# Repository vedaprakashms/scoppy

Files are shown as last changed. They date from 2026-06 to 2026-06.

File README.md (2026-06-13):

# scoppy
PI Pico ossciloscope using simple components

The project contains multiple directory, each with its own kind of Scopy, i.e Surface mountable, through hole, etc...

The Directory names are self explanatory. 

# IMAGES

## Scoppy SMD Single sided PCB
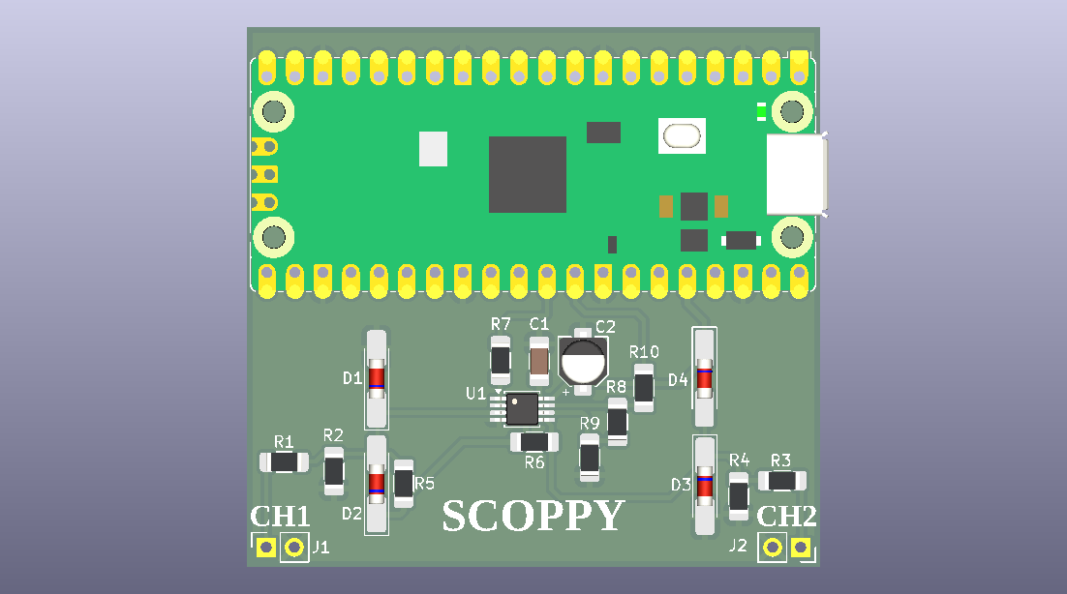
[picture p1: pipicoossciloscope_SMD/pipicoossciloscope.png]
SCOPPY SMD single sided Single sided pcb front view


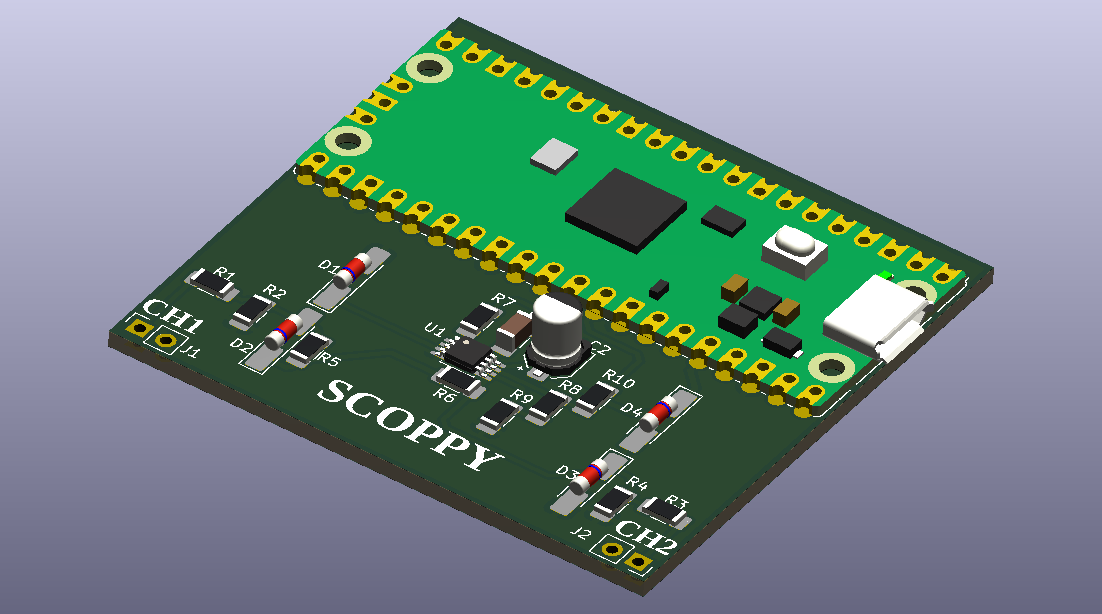
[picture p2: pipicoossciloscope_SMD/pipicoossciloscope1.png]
SCOPPY SMD Single Side Ortho Single sided PCB Ortho View.


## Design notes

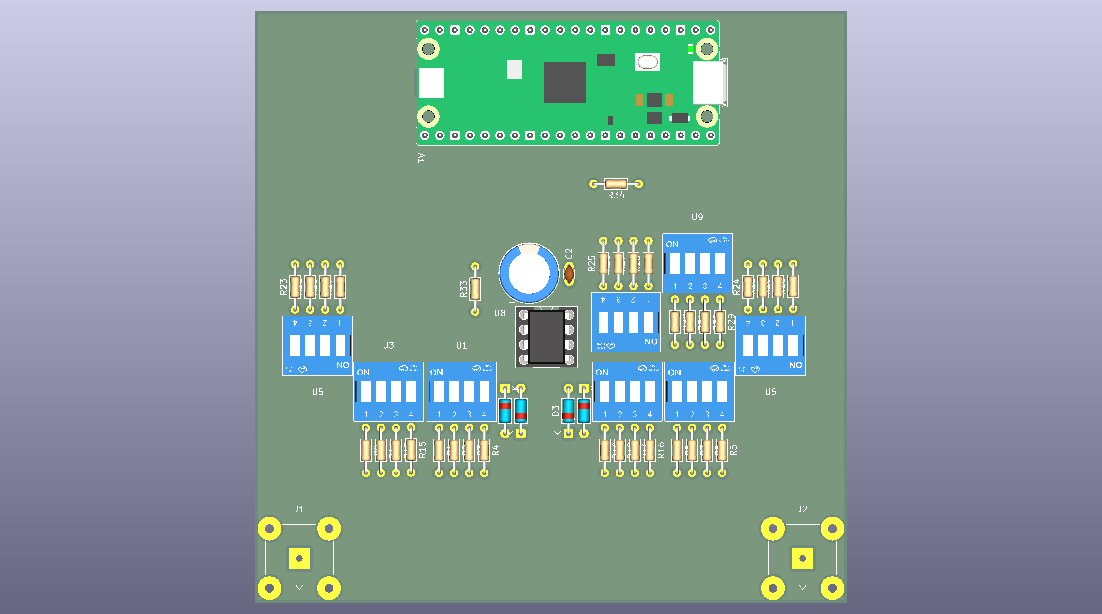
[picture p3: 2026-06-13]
PiPicoOssciloscope_THT/PiPicoOssciloscope_THT.png

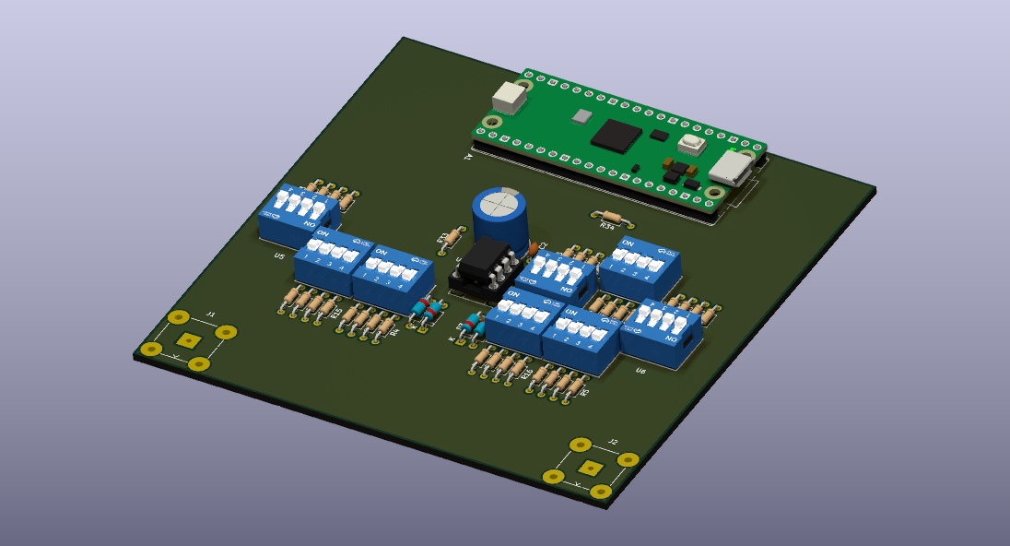
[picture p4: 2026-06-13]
PiPicoOssciloscope_THT/PiPicoOssciloscope_THT_1.png

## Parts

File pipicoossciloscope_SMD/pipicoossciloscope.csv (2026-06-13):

Reference | Qty | Value | DNP | Exclude from BOM | Exclude from Board | Footprint | Datasheet
A1 | 1 | RaspberryPi_Pico |  |  |  | Module:RaspberryPi_Pico_Common_Unspecified | https://datasheets.raspberrypi.com/pico/pico-datasheet.pdf
C1 | 1 | C |  |  |  | Capacitor_SMD:C_1206_3216Metric_Pad1.33x1.80mm_HandSolder
C2 | 1 | C_Polarized |  |  |  | Capacitor_SMD:CP_Elec_4x5.4
D1,D2,D3,D4 | 4 | LL4148 |  |  |  | Diode_SMD:D_MiniMELF_Handsoldering | http://www.vishay.com/docs/85557/ll4148.pdf
J1,J2 | 2 | Conn_01x02_Socket |  |  |  | Connector_PinSocket_2.54mm:PinSocket_1x02_P2.54mm_Vertical
R1,R2,R3,R4,R5,R6,R7,R8,R9,R10 | 10 | R |  |  |  | Resistor_SMD:R_1206_3216Metric_Pad1.30x1.75mm_HandSolder
U1 | 1 | MCP6002-xMS |  |  |  | Package_SO:MSOP-8_3x3mm_P0.65mm | http://ww1.microchip.com/downloads/en/DeviceDoc/21733j.pdf

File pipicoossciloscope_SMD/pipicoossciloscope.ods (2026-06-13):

Reference | Qty | Value | Individual cost | Total Cost | DNP | Exclude from BOM | Exclude from Board | Footprint | Datasheet
A1 | 1 | RaspberryPi_Pico | 250 | 250 |  |  |  | Module:RaspberryPi_Pico_Common_Unspecified | https://datasheets.raspberrypi.com/pico/pico-datasheet.pdf
C1 | 1 | C | 1 | 1 |  |  |  | Capacitor_SMD:C_1206_3216Metric_Pad1.33x1.80mm_HandSolder
C2 | 1 | C_Polarized | 2 | 2 |  |  |  | Capacitor_SMD:CP_Elec_4x5.4
D1,D2,D3,D4 | 4 | LL4148 | 1 | 4 |  |  |  | Diode_SMD:D_MiniMELF_Handsoldering | http://www.vishay.com/docs/85557/ll4148.pdf
J1,J2 | 2 | Conn_01x02_Socket | 0 | 0 |  |  |  | Connector_PinSocket_2.54mm:PinSocket_1x02_P2.54mm_Vertical
R1,R2,R3,R4,R5,R6,R7,R8,R9,R10 | 10 | R | 0.2 | 2 |  |  |  | Resistor_SMD:R_1206_3216Metric_Pad1.30x1.75mm_HandSolder
U1 | 1 | MCP6002-xMS | 40 | 40 |  |  |  | Package_SO:MSOP-8_3x3mm_P0.65mm | http://ww1.microchip.com/downloads/en/DeviceDoc/21733j.pdf
 | 1 | Others | 200 | 200
 |  |  |  | 499

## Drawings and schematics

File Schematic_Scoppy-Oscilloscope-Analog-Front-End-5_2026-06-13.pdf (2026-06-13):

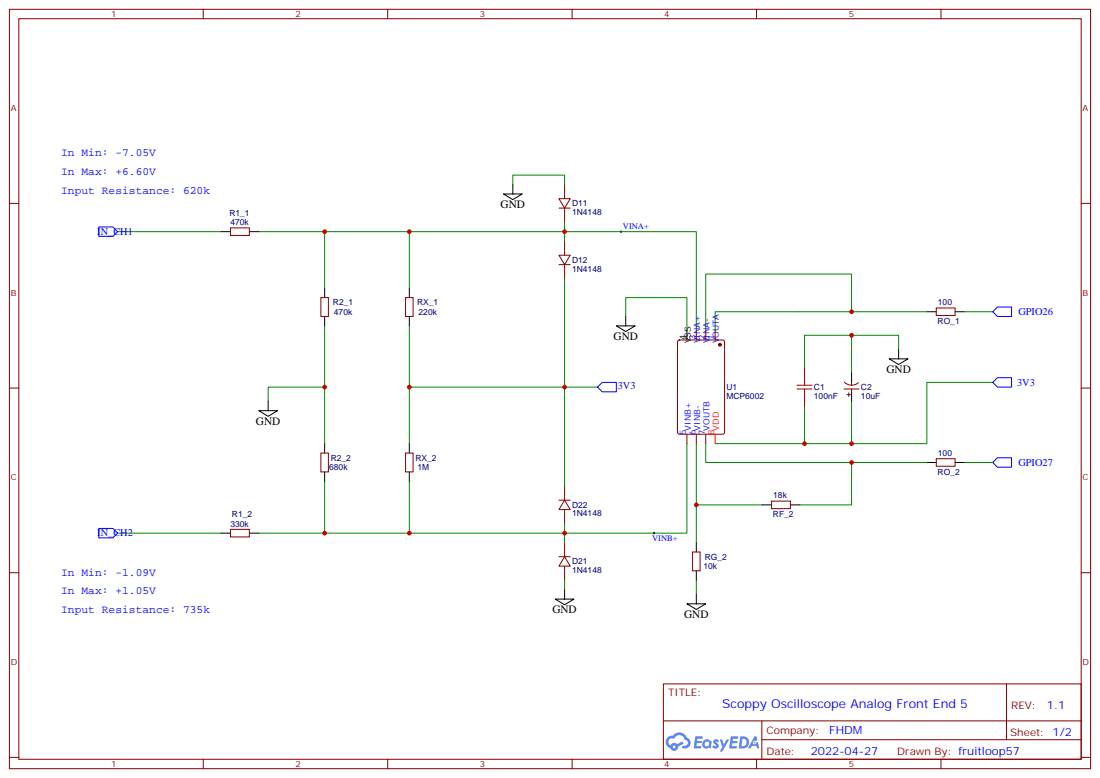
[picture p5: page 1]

MCP6282, MCP6292

## Examples of other voltage ranges

## Alternative Op-Amps

GAIN: 1.67

Note: 'In Min' and 'In Max' are the values you enter as the voltage ranges in the Scoppy app

In Min: -10.2V
In Max: +10.1V
Input Resistance: 812k

R1: 680k
R2: 330k
RX: 220k
GAIN: Unity
RF: NONE
RG: NONE | RG: NONE | RG: 22k | RG: 15k RF: 10k

RX: 560k

R2: 680k

R1: 330k

Input Resistance: 637k

In Max: +2.16V

In Min: -1.94V

RF: 12k

GAIN: 1.55

RX: 470k

R2: 470k

R1: 470k

Input Resistance: 705k

In Max: +3.11V

In Min: -3.30V

RF: NONE

GAIN: Unity

RX: 220k

R2: 680k

R1: 330k

Input Resistance: 496k

In Max: +4.01V

In Min: -4.95V
A | A
B | B
C | C
D | D

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
TITLE:
Scoppy Oscilloscope Analog Front End 5 | REV: 1.0
Date: | 2022-05-17

Sheet: 2/2
Drawn By: fruitloop57

Company: FHDM
https://github.com/fhdm-dev/scoppy

RG: NONE

RF: NONE

GAIN: Unity

RX: 150k

R2: 180k

R1: 820k

Input Resistance: 902k

In Max: +18.3V

In Min: -18.0V

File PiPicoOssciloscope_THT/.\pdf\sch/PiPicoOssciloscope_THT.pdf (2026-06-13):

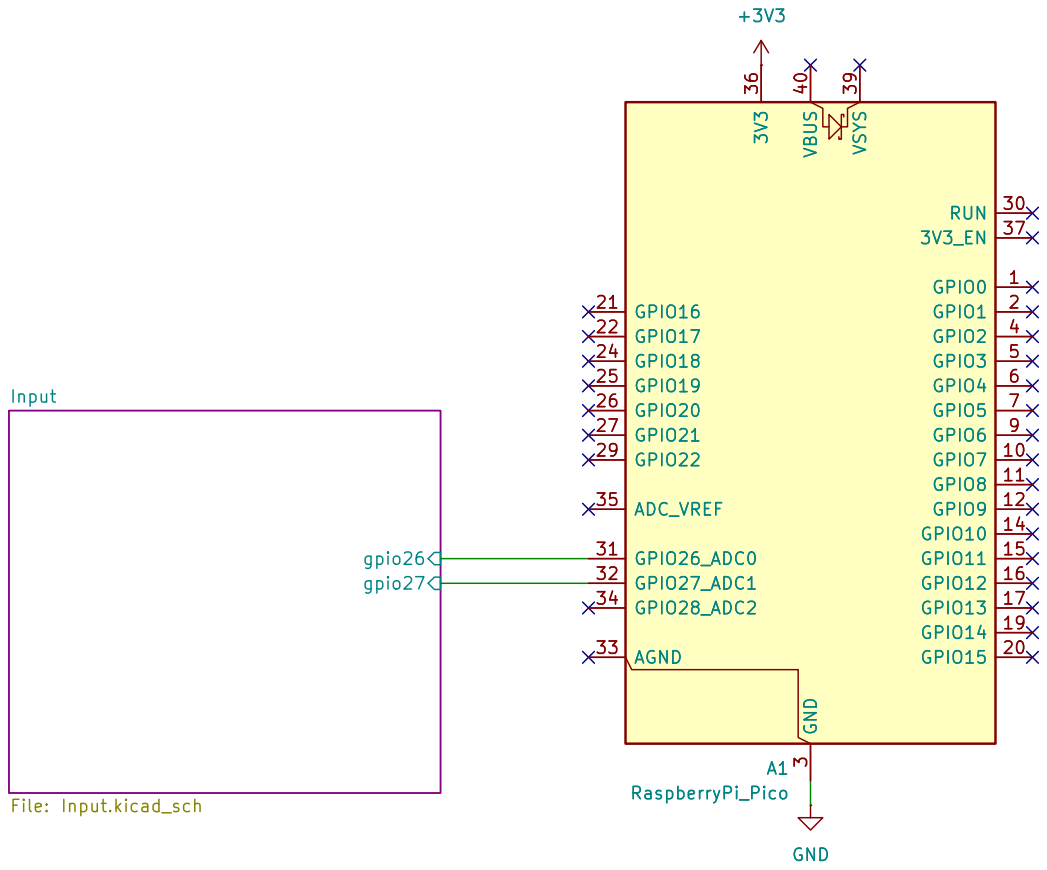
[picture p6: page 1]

Size: A4 | Rev:
KiCad E.D.A. 10.0.3 | Id: 1/2

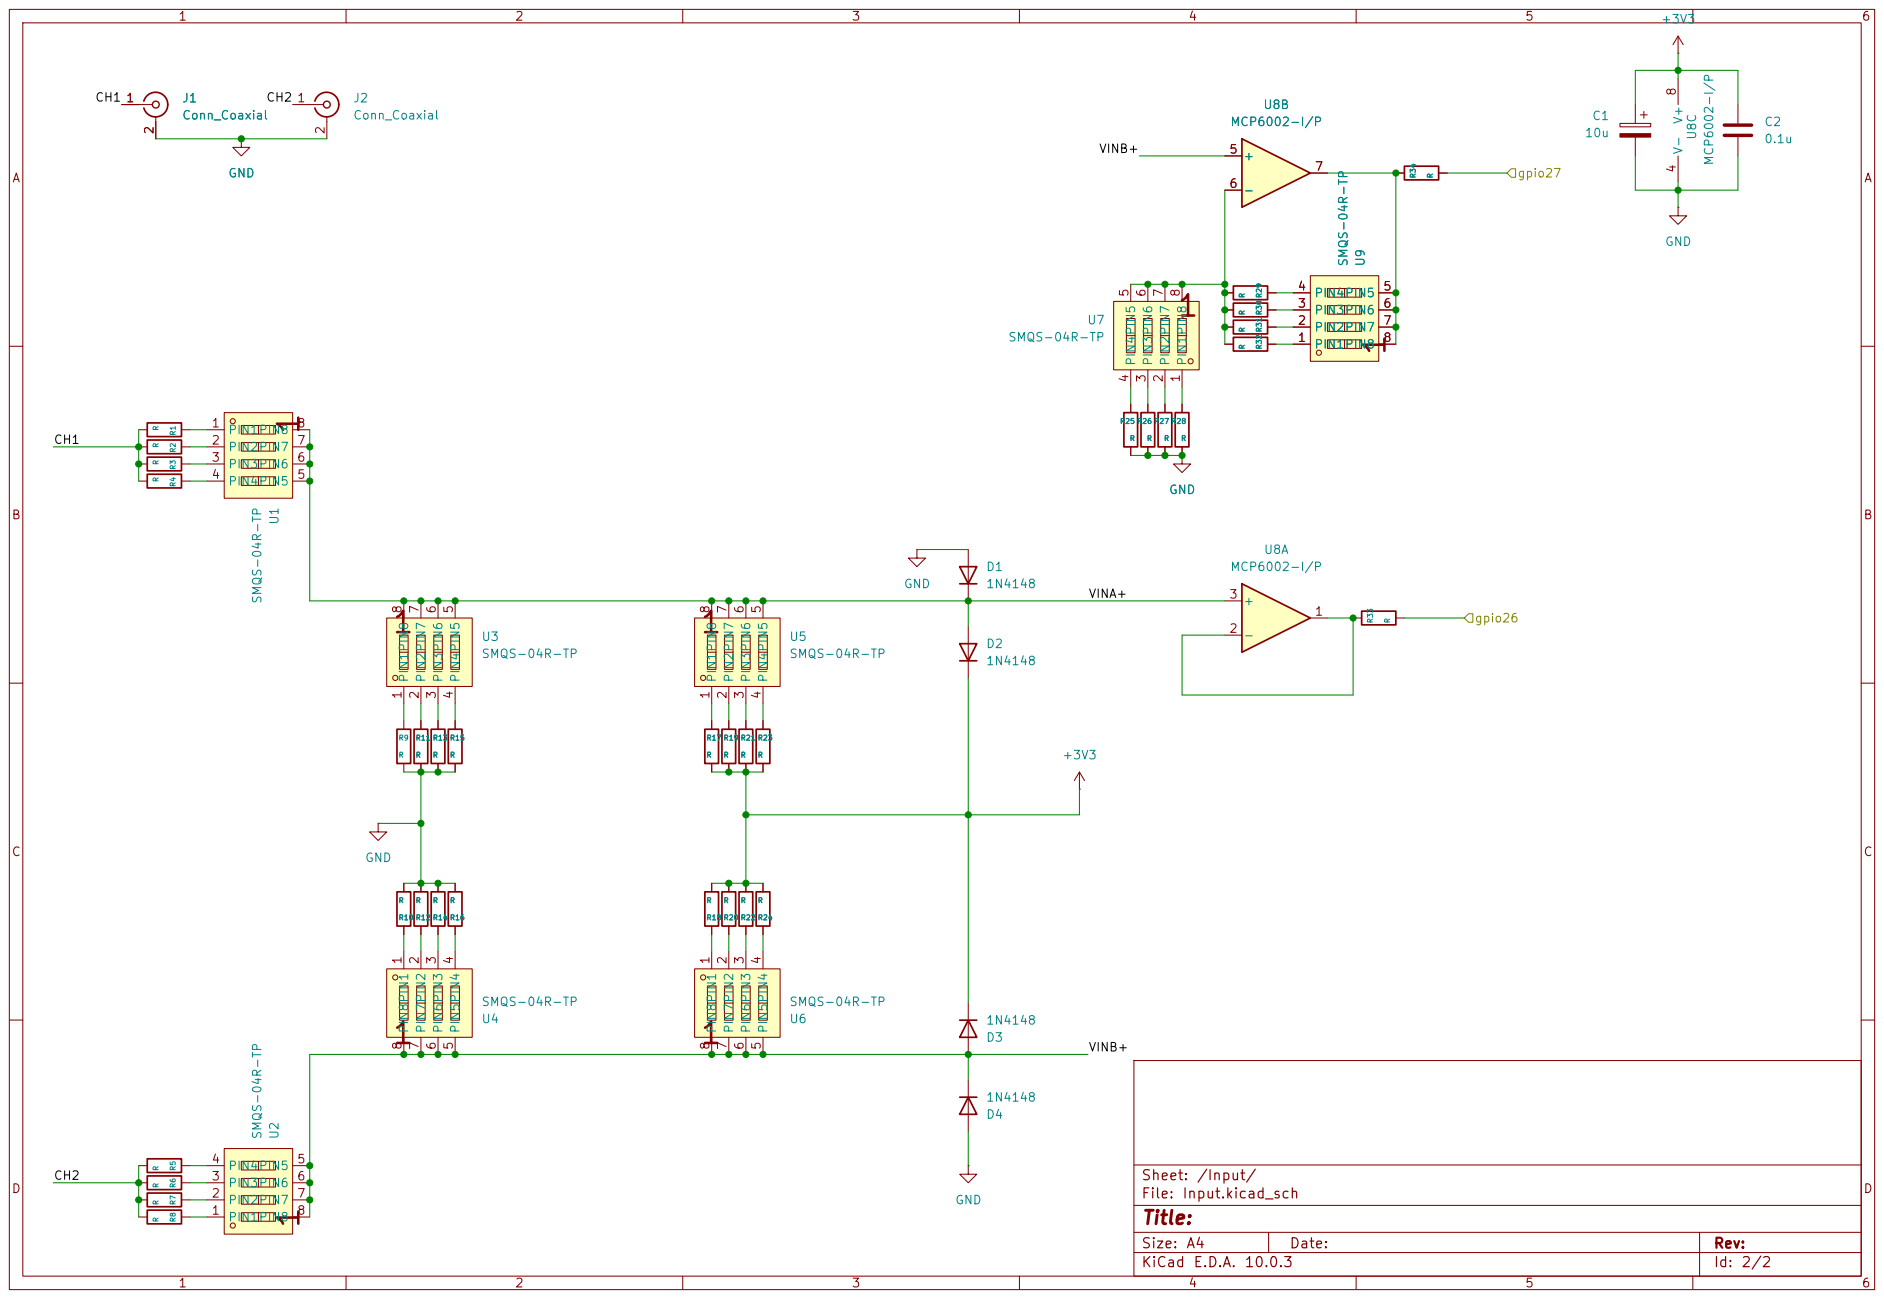
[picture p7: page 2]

Size: A4 | Rev:
KiCad E.D.A. 10.0.3 | Id: 2/2

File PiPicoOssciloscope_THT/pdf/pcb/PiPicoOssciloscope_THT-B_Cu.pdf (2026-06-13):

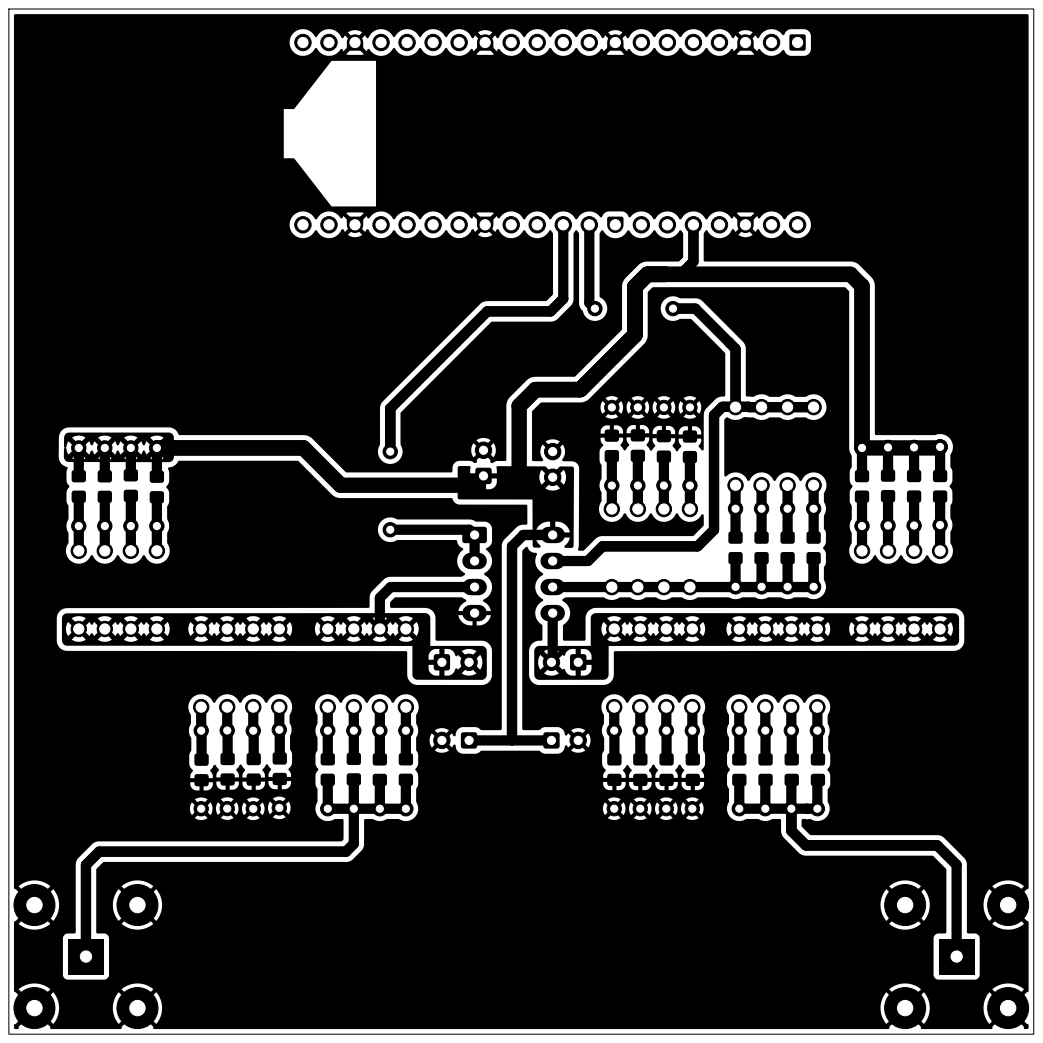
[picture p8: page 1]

Size: A4 | Rev:
KiCad E.D.A. 10.0.3 | Id: 2/9

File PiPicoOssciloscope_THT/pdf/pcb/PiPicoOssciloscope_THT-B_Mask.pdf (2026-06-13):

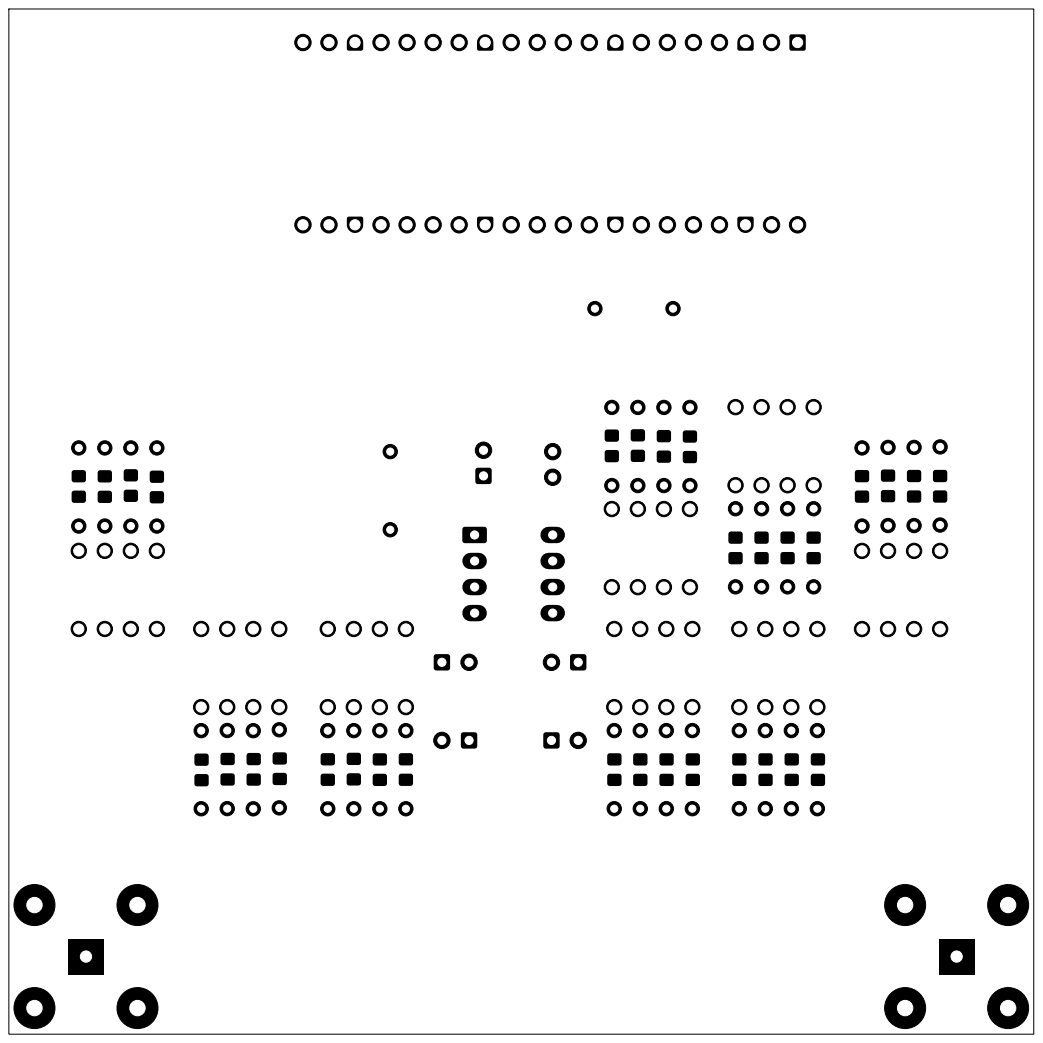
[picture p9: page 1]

Size: A4 | Rev:
KiCad E.D.A. 10.0.3 | Id: 8/9

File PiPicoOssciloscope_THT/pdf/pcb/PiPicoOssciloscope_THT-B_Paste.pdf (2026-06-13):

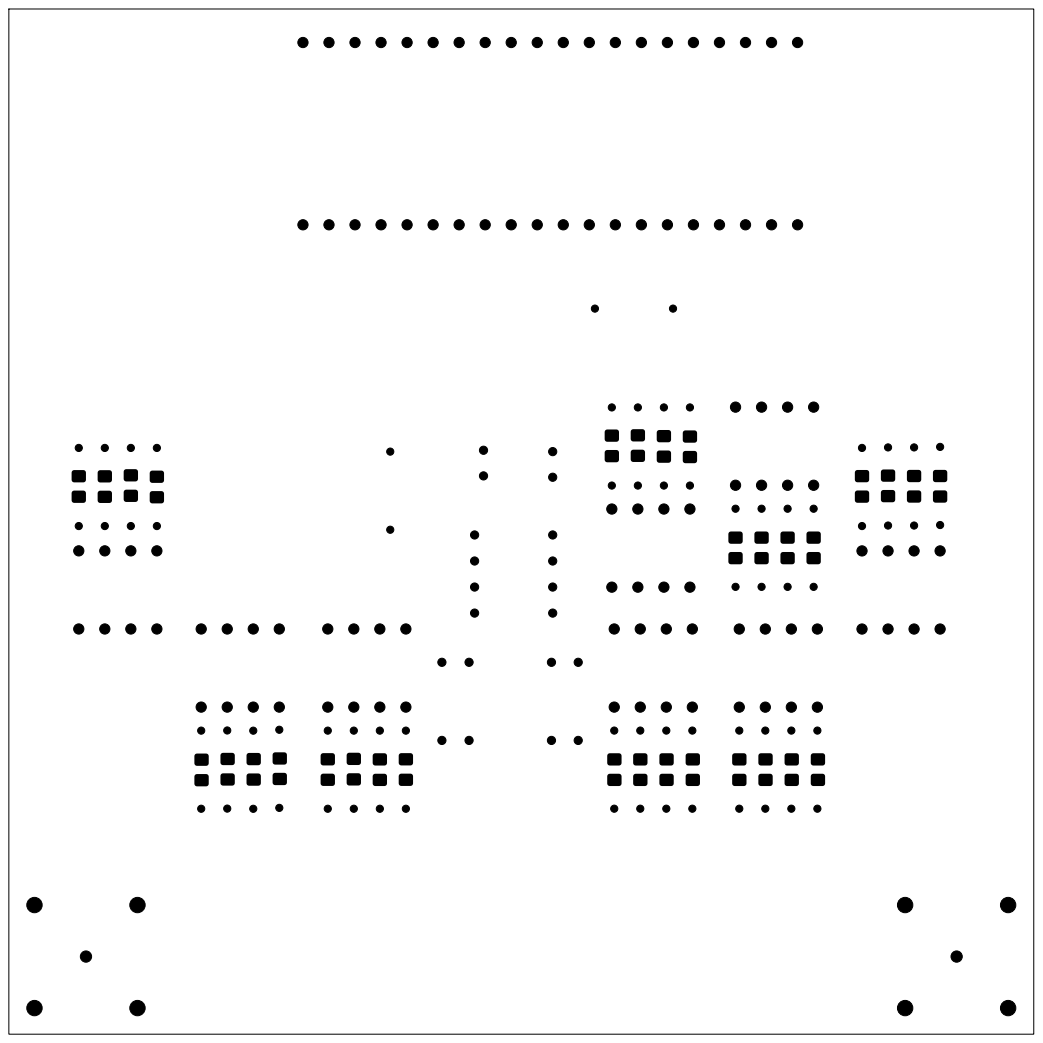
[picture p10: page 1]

Size: A4 | Rev:
KiCad E.D.A. 10.0.3 | Id: 4/9

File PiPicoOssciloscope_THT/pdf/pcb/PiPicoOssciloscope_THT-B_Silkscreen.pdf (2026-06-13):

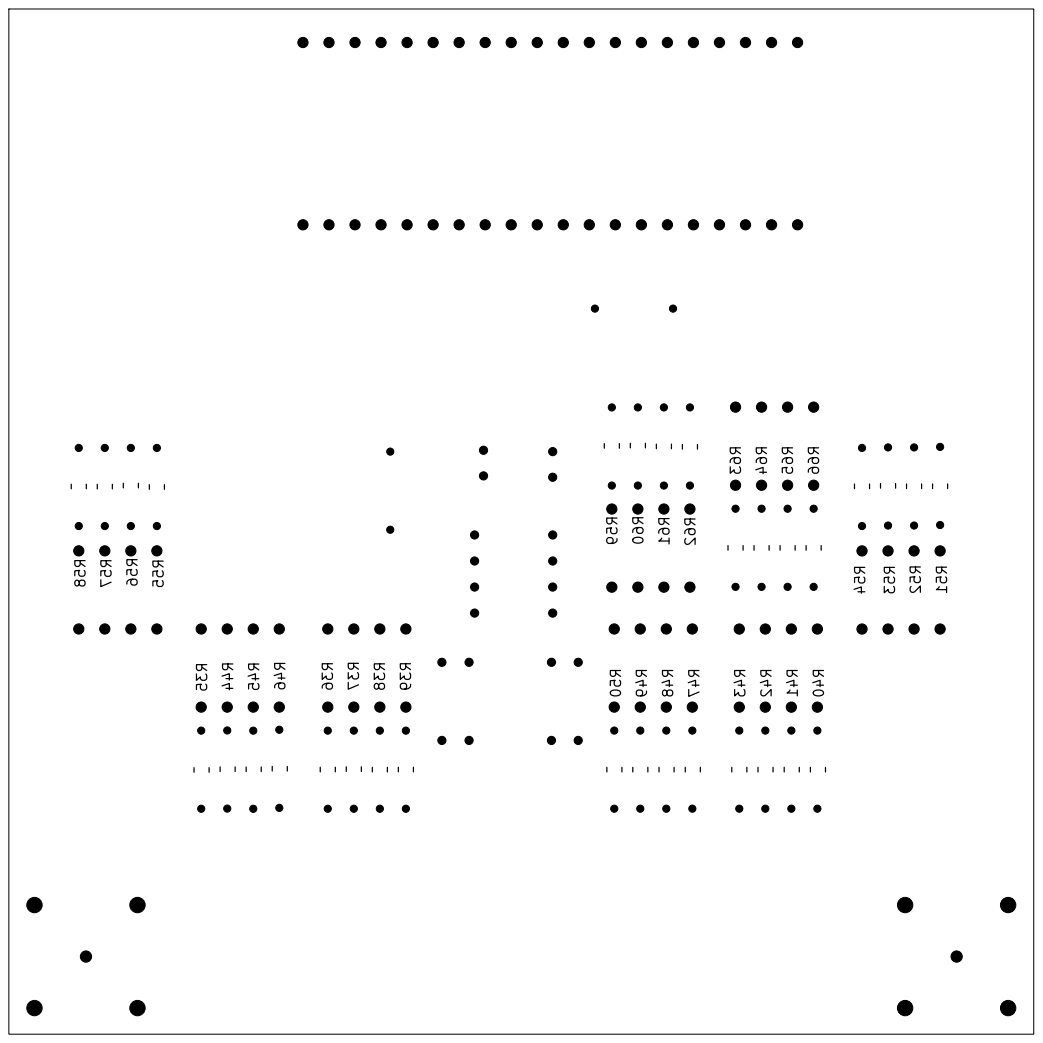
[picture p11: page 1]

Size: A4 | Rev:
KiCad E.D.A. 10.0.3 | Id: 6/9

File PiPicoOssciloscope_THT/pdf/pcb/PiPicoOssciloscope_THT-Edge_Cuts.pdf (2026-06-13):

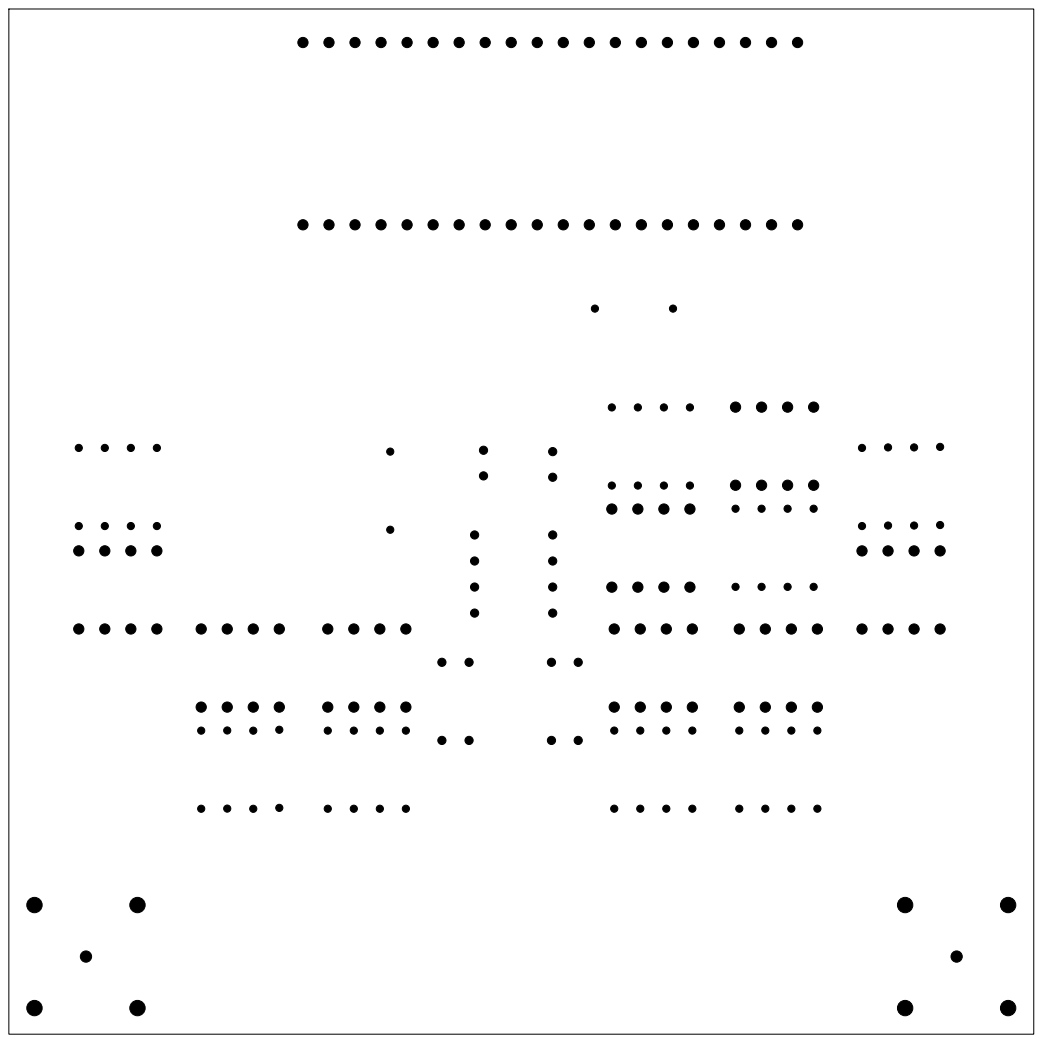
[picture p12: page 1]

Size: A4 | Rev:
KiCad E.D.A. 10.0.3 | Id: 9/9

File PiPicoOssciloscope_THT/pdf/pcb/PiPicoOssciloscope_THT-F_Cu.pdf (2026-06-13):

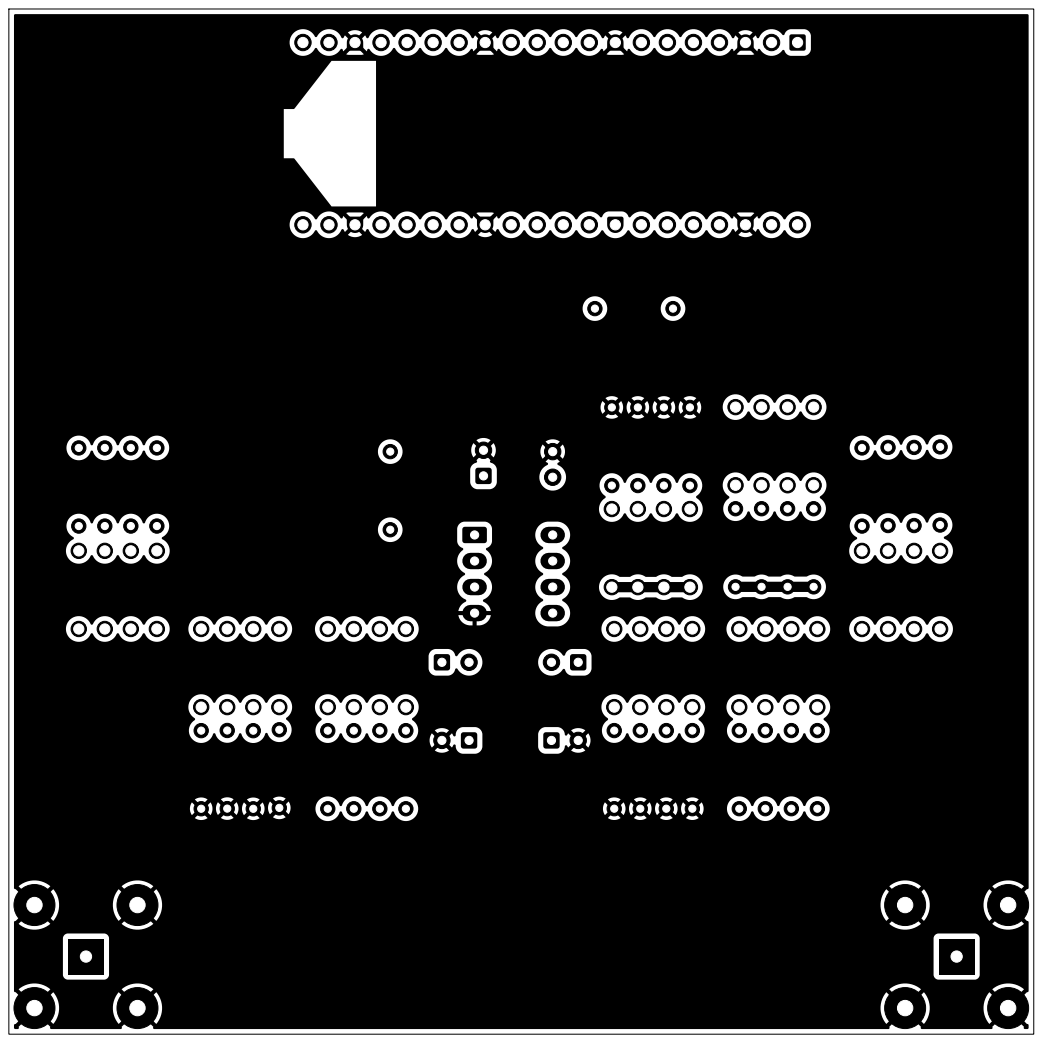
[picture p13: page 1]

Size: A4 | Rev:
KiCad E.D.A. 10.0.3 | Id: 1/9

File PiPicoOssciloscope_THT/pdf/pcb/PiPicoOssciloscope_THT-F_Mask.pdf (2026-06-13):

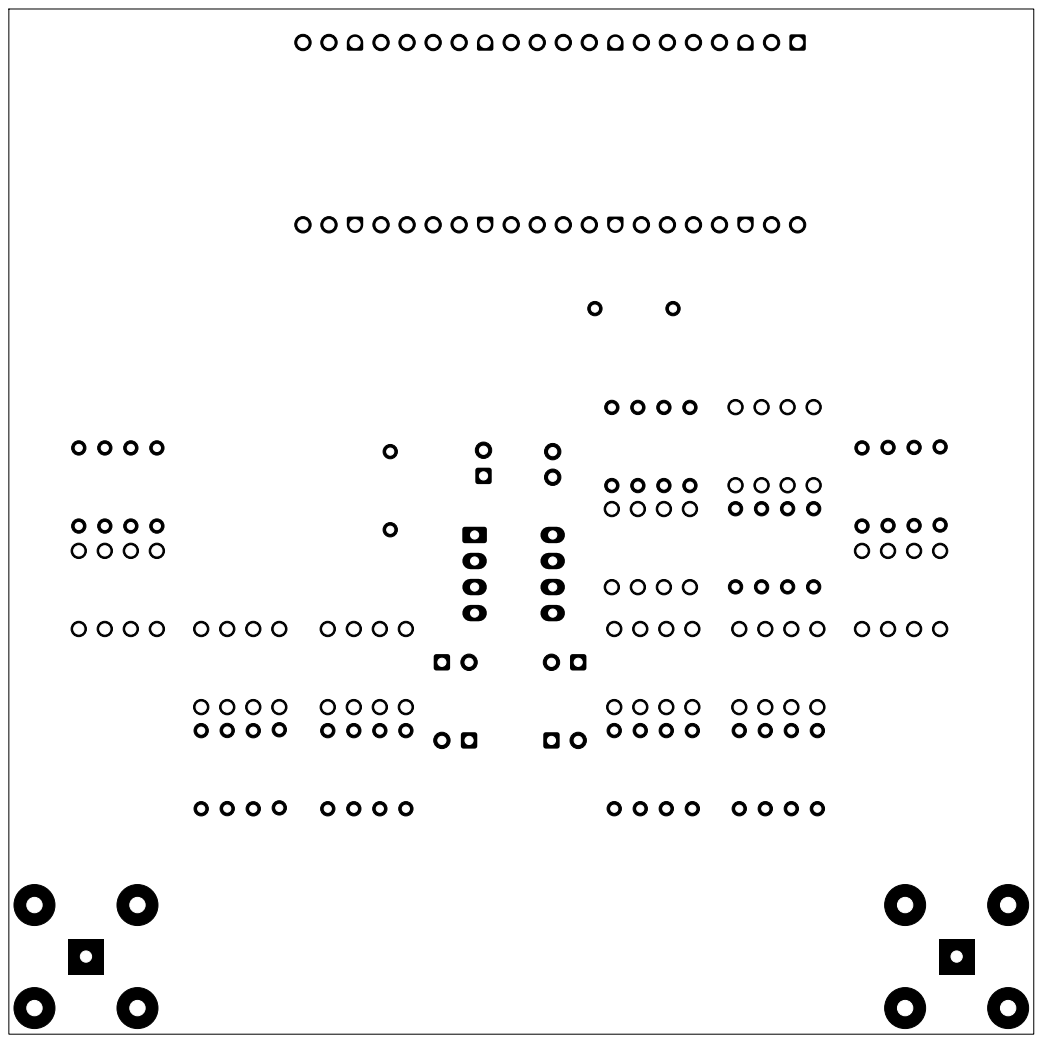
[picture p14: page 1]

Size: A4 | Rev:
KiCad E.D.A. 10.0.3 | Id: 7/9

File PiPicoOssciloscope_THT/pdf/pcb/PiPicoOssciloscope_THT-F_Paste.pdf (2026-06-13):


Size: A4 | Rev:
KiCad E.D.A. 10.0.3 | Id: 3/9

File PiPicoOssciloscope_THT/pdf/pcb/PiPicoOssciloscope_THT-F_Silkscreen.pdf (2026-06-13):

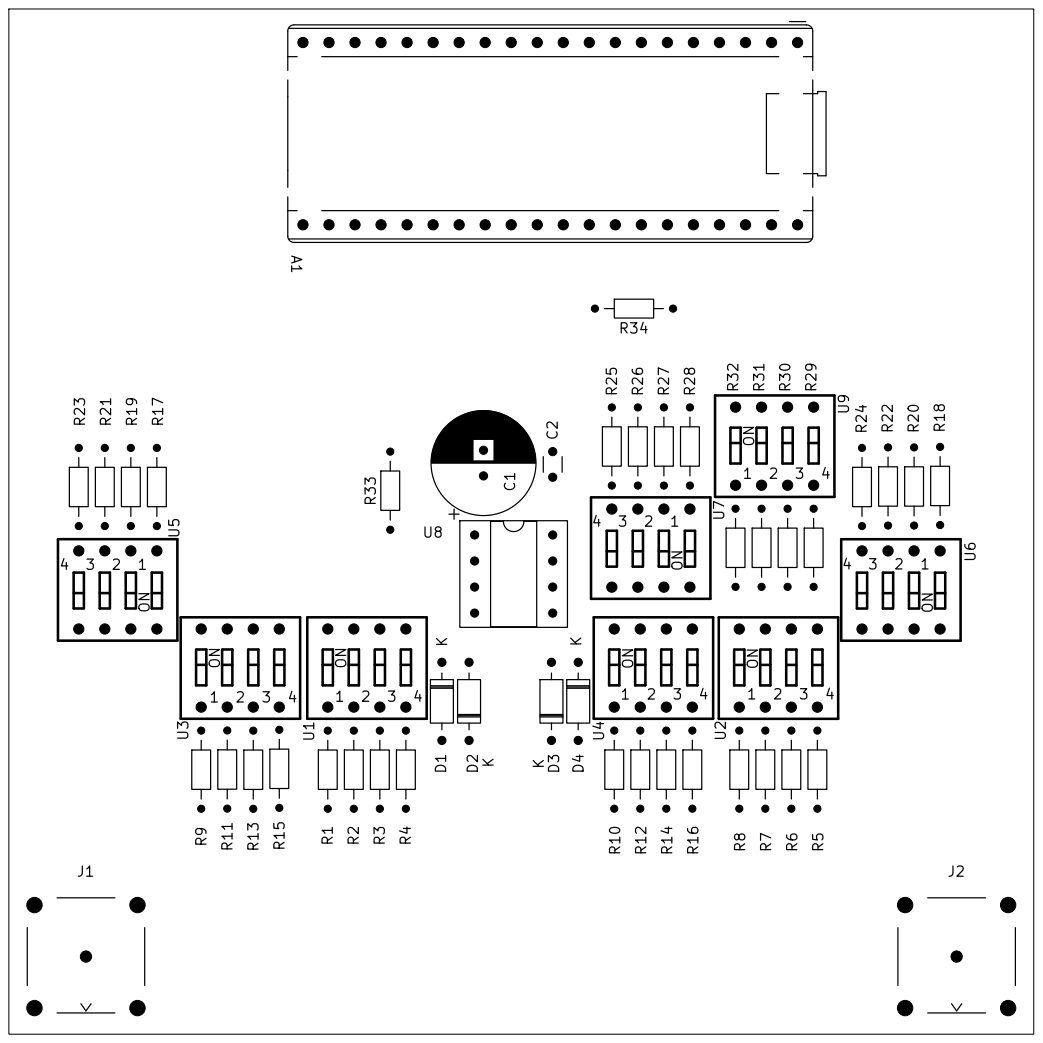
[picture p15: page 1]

Size: A4 | Rev:
KiCad E.D.A. 10.0.3 | Id: 5/9

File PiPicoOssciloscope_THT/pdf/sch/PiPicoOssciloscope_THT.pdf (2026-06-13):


Size: A4 | Rev:
KiCad E.D.A. 10.0.3 | Id: 1/2

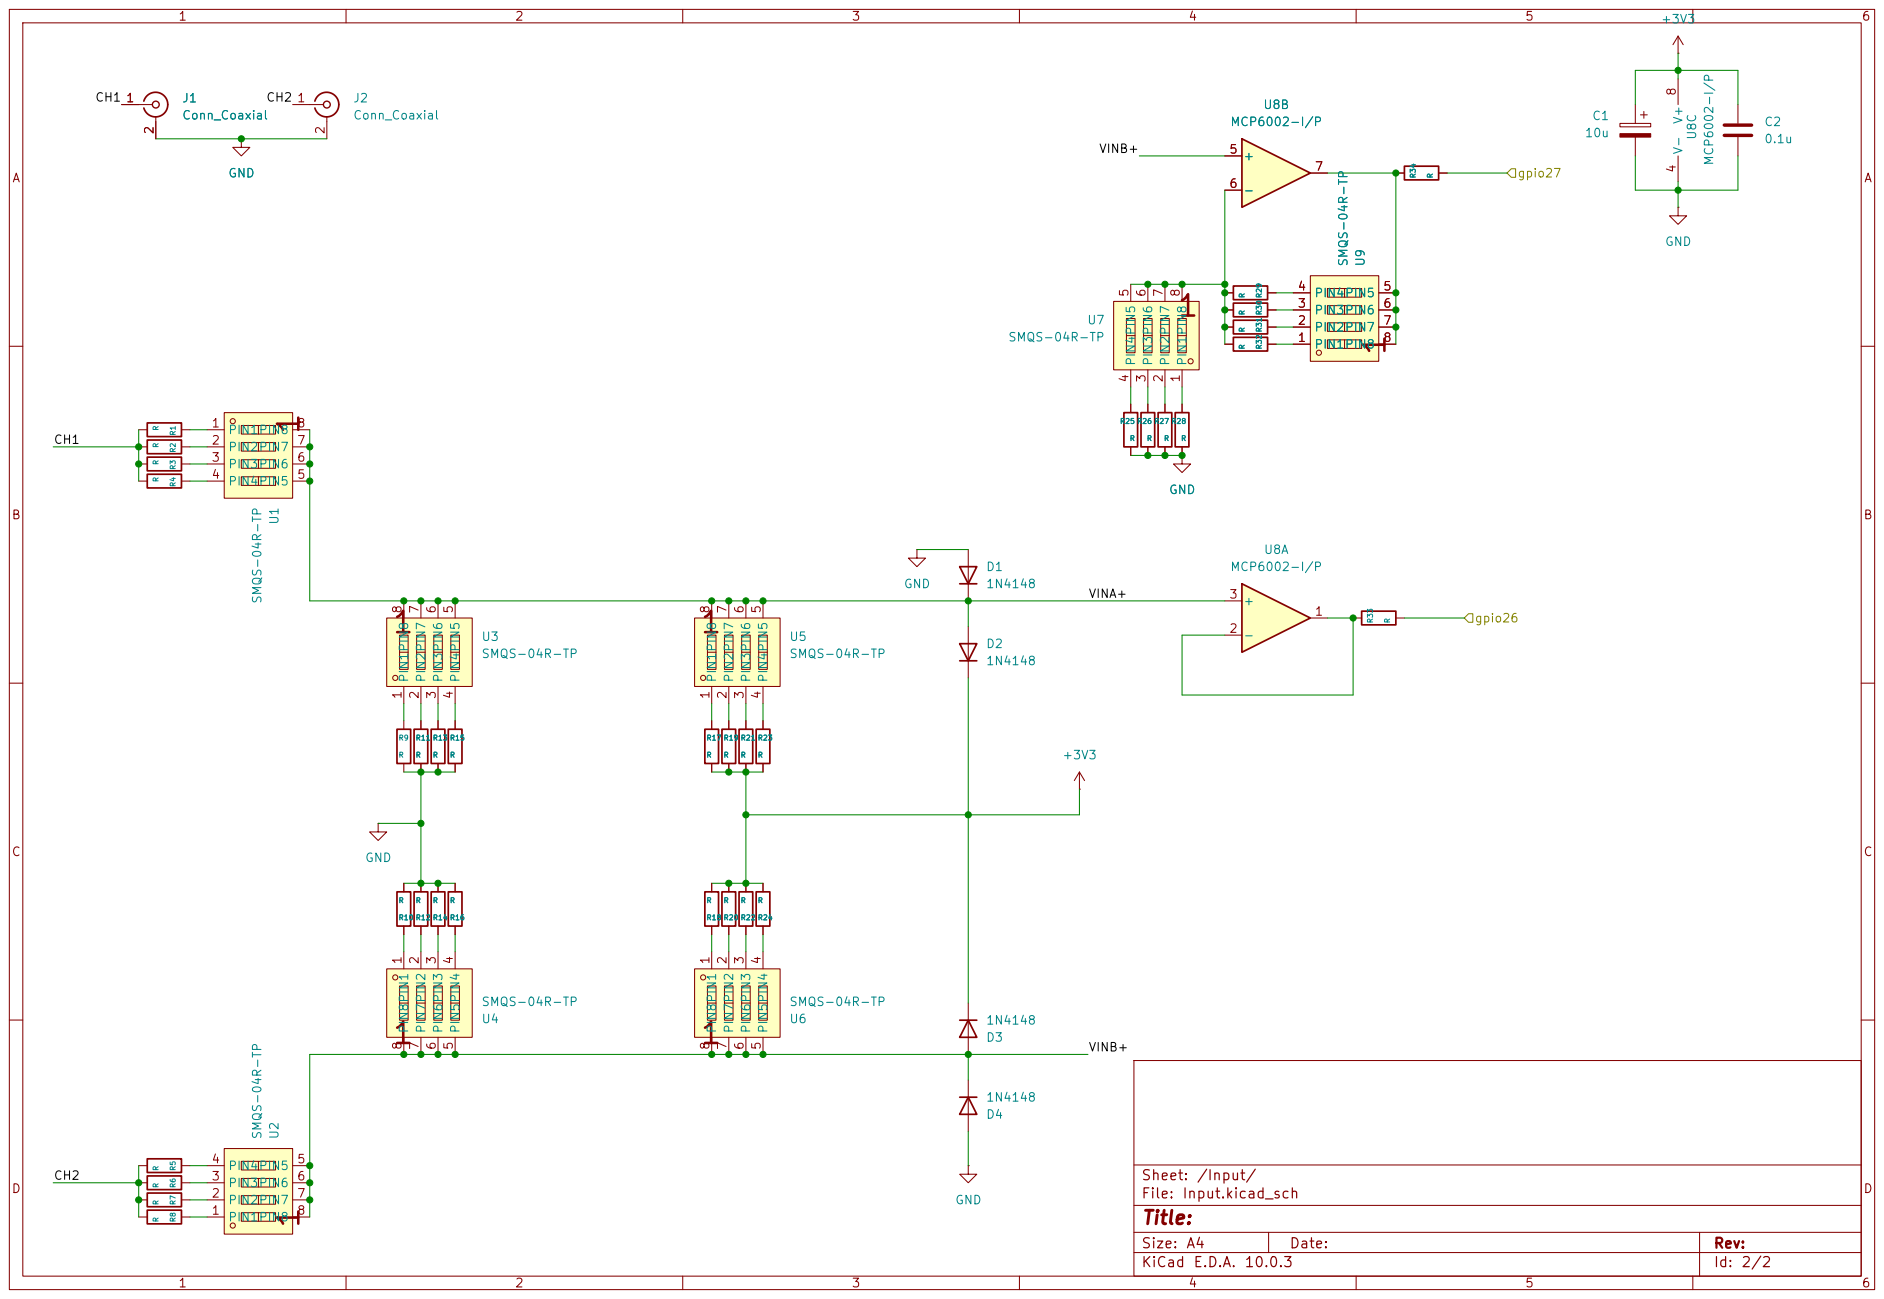
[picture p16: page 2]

Size: A4 | Rev:
KiCad E.D.A. 10.0.3 | Id: 2/2

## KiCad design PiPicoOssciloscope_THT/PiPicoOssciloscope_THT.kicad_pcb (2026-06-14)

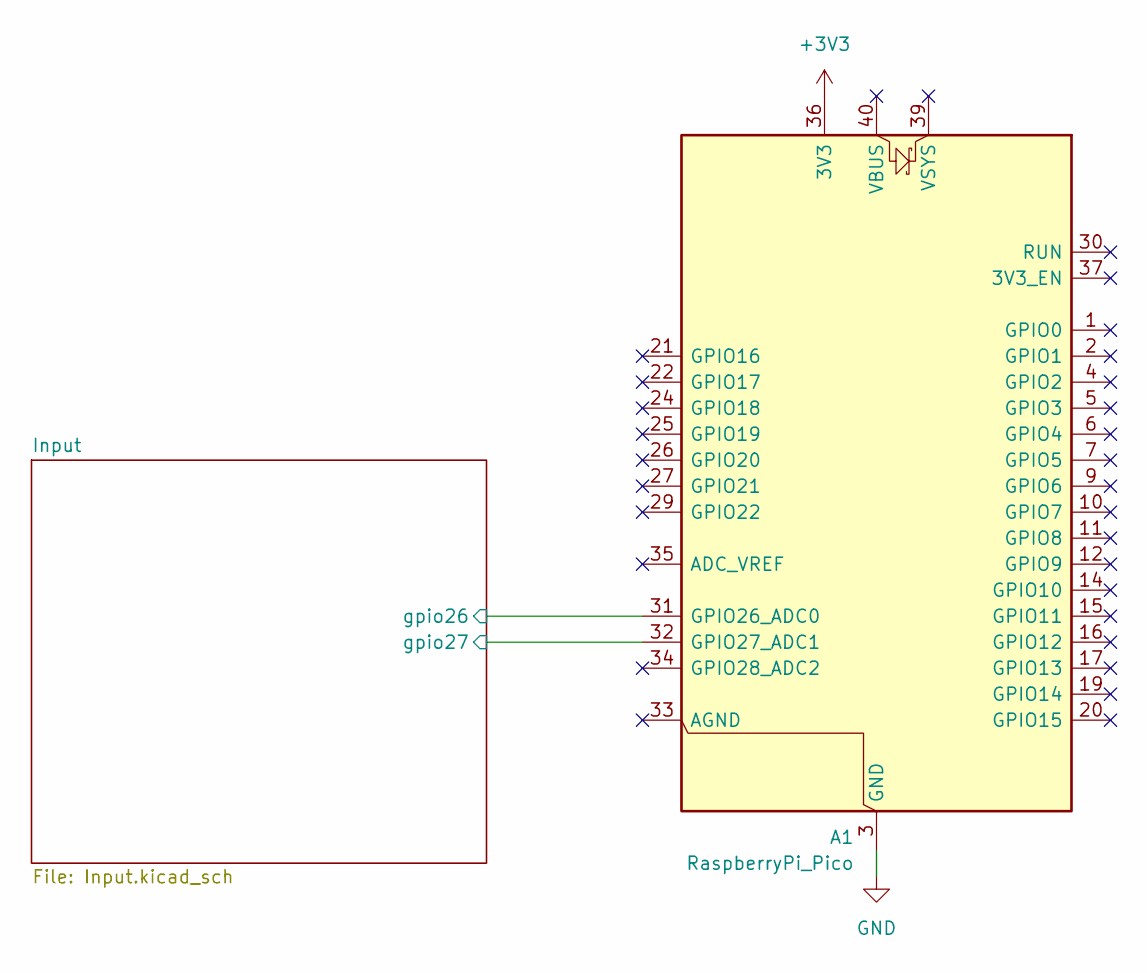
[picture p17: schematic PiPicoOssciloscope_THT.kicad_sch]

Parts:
A1: RaspberryPi_Pico; RaspberryPi_Pico_Common_THT

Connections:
+3V3: A1.36 (3V3); also elsewhere on the board
/Input/gpio26: A1.31 (GPIO26_ADC0); also elsewhere on the board
/Input/gpio27: A1.32 (GPIO27_ADC1); also elsewhere on the board
GND: A1.3 (GND), A1.8 (GND), A1.13 (GND), A1.18 (GND), A1.23 (GND), A1.28 (GND), A1.38 (GND); also elsewhere on the board

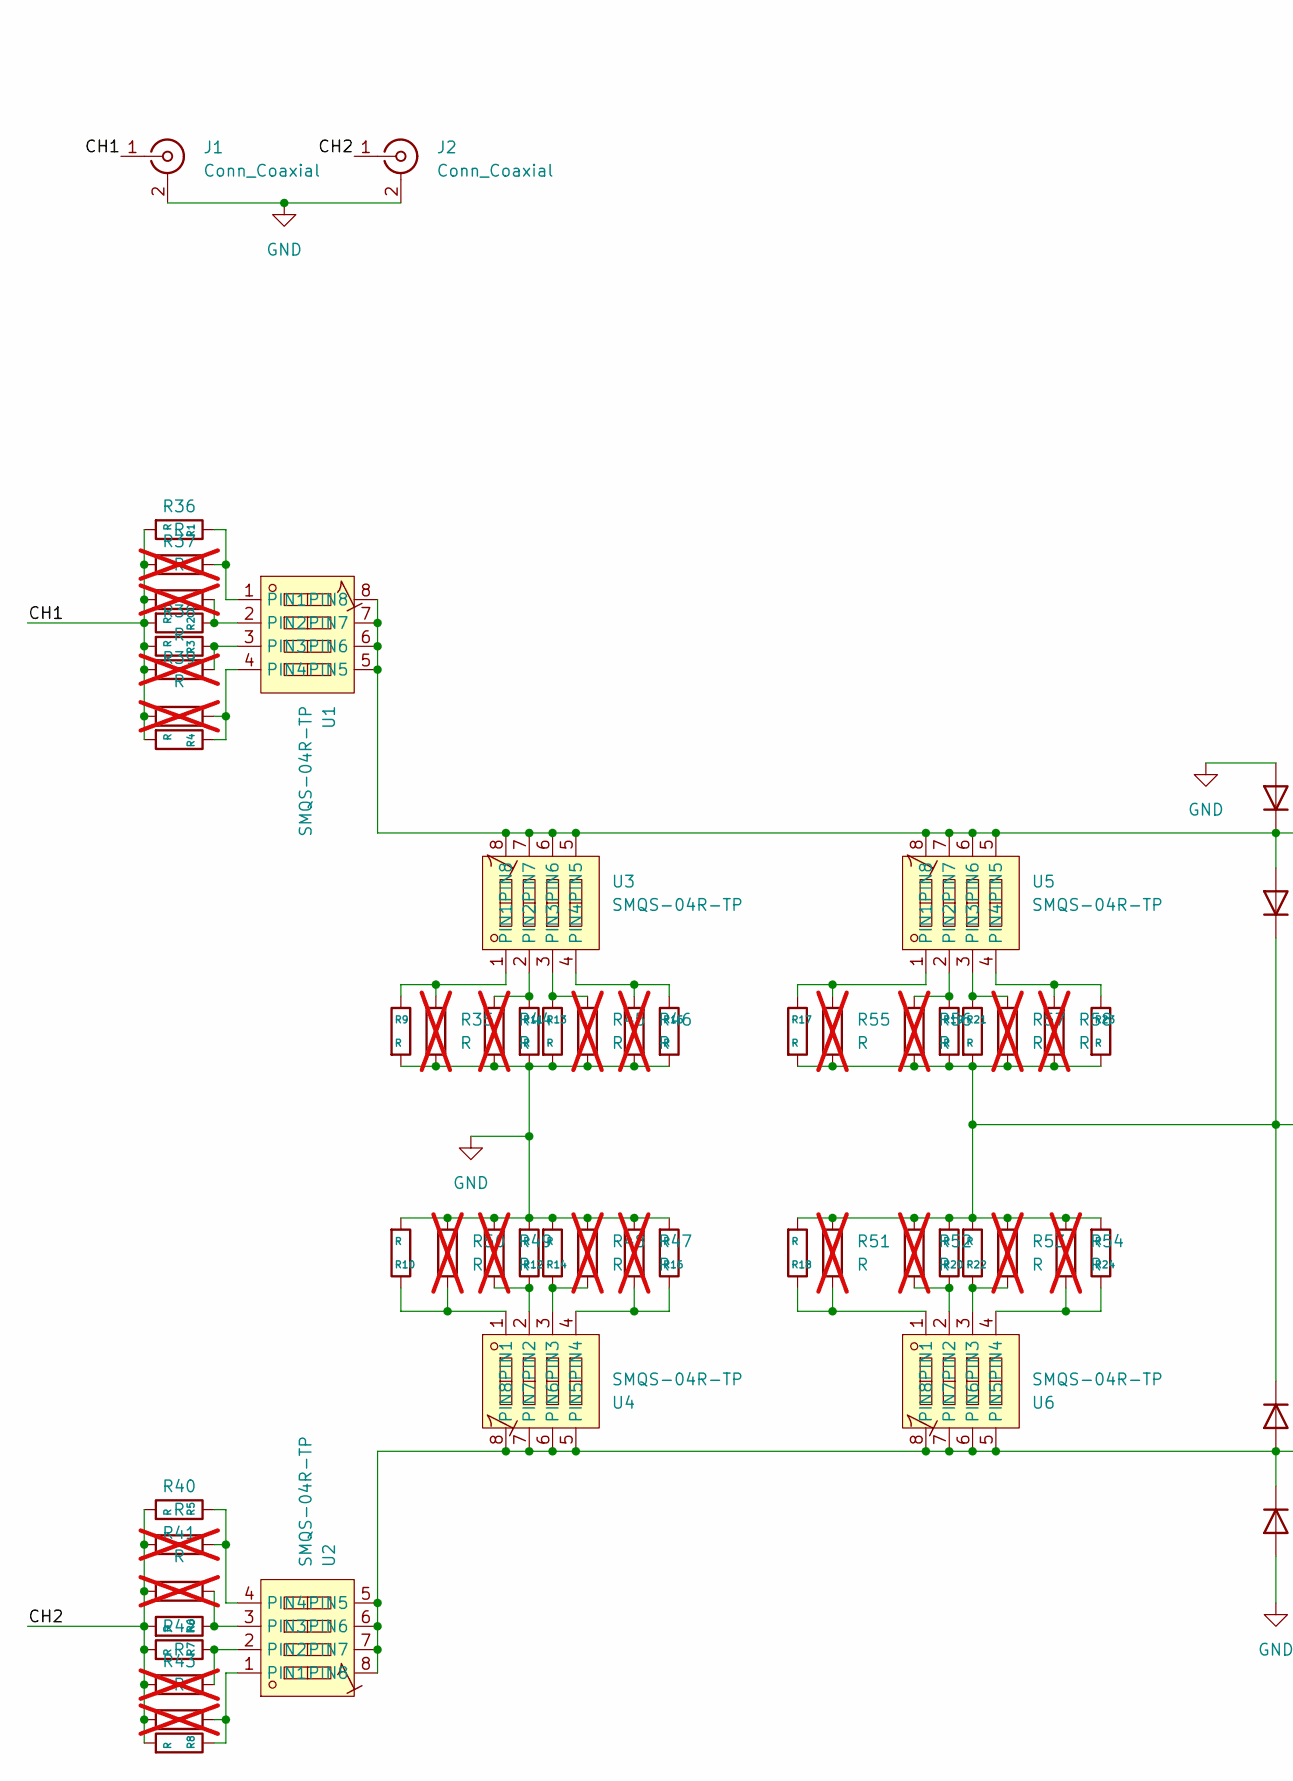
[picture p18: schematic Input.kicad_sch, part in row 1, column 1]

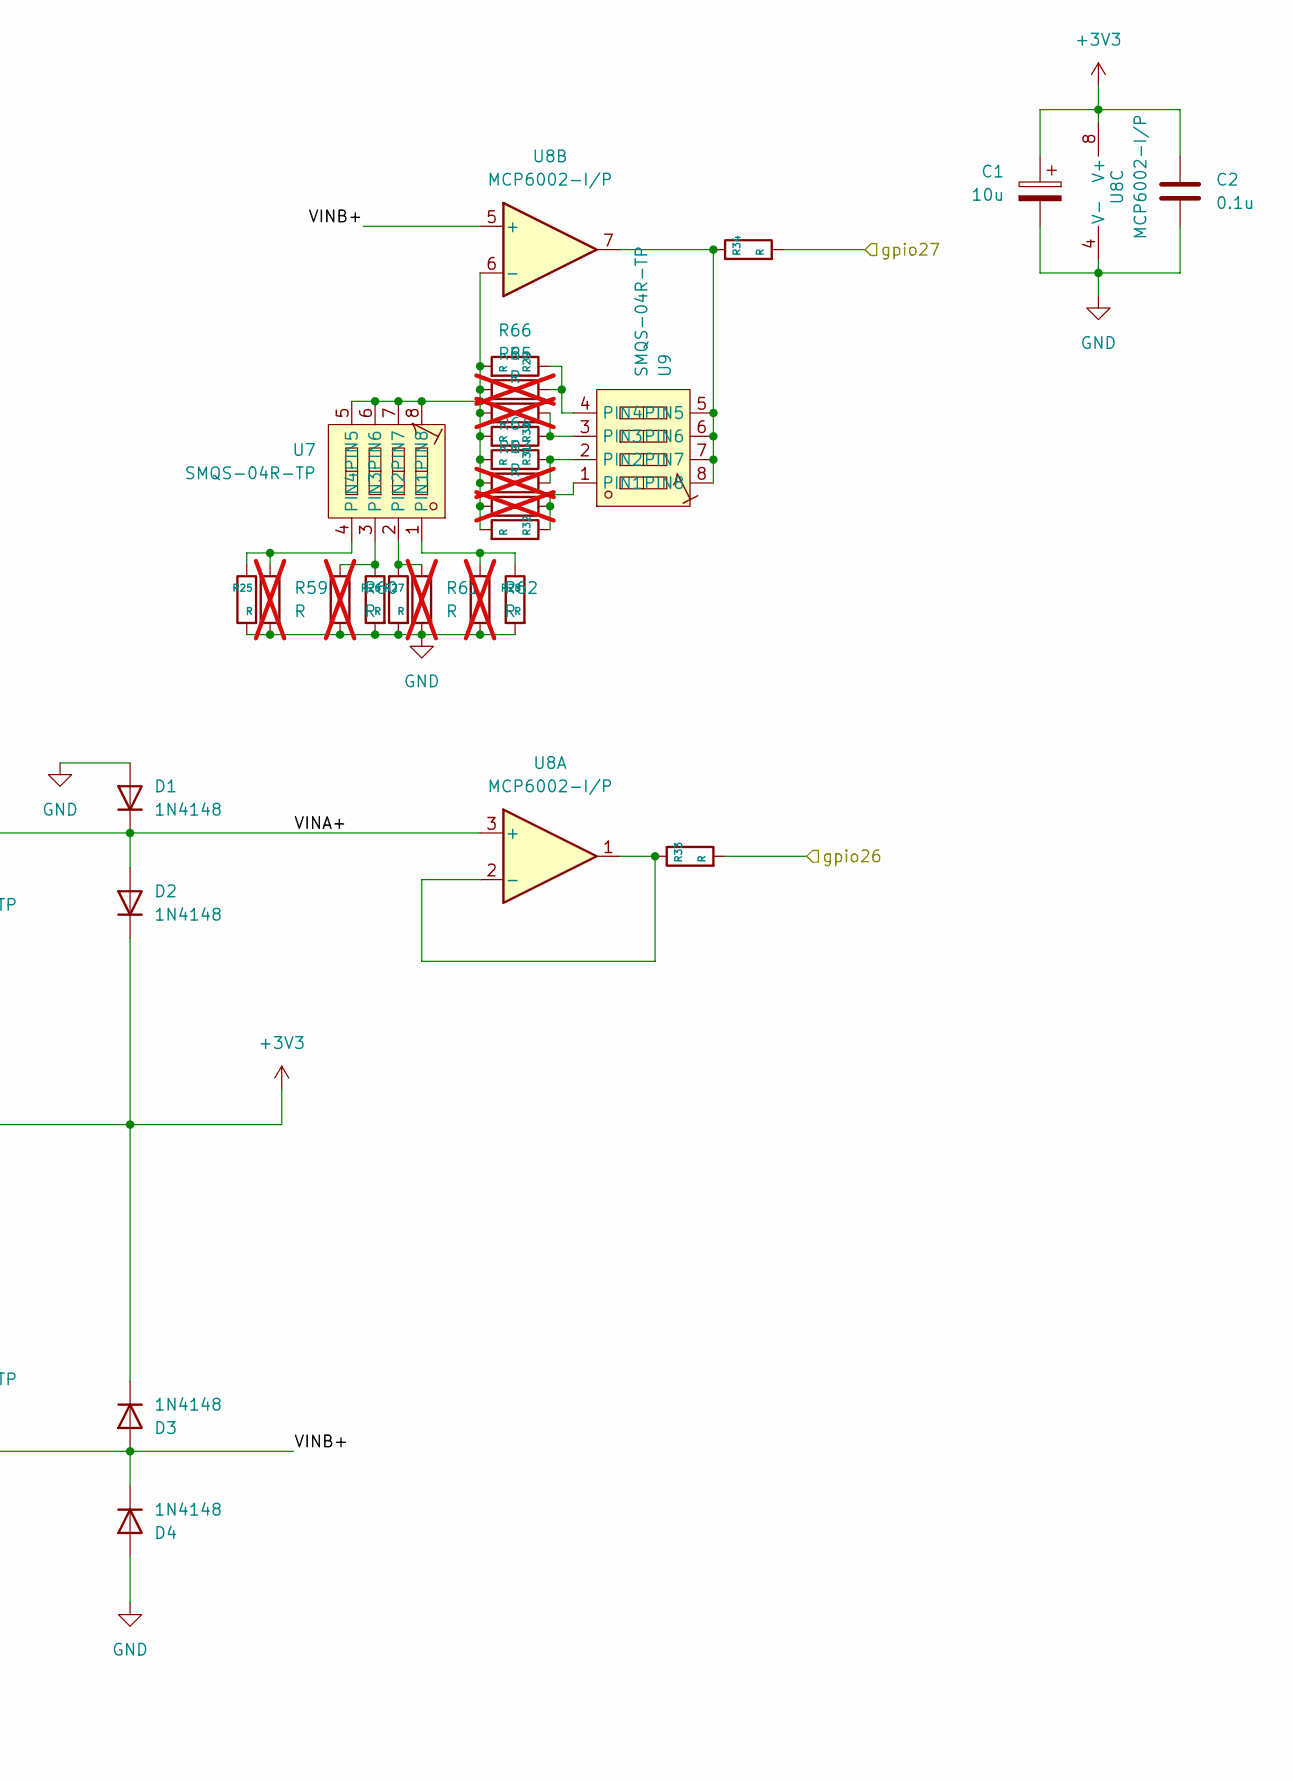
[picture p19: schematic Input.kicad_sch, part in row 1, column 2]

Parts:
C1: 10u; CP_Radial_D10.0mm_P2.50mm
C2: 0.1u; C_Disc_D3.0mm_W1.6mm_P2.50mm
D1, D2, D3, D4: 1N4148; D_DO-35_SOD27_P7.62mm_Horizontal
J1, J2: Conn_Coaxial; BNC_Amphenol_B6252HB-NPP3G-50_Horizontal
R1, R2, R3, R4, R5, R6, R7, R8, R9, R10, R11, R12, R13, R14, R15, R16, R17, R18, R19, R20, R21, R22, R23, R24, R25, R26, R27, R28, R29, R30, R31, R32, R33, R34: R; R_Axial_DIN0204_L3.6mm_D1.6mm_P7.62mm_Horizontal
R35, R36, R37, R38, R39, R40, R41, R42, R43, R44, R45, R46, R47, R48, R49, R50, R51, R52, R53, R54, R55, R56, R57, R58, R59, R60, R61, R62, R63, R64, R65, R66: R; R_0805_2012Metric_Pad1.20x1.40mm_HandSolder; not fitted
U1, U2, U3, U4, U5, U6, U7, U9: SMQS-04R-TP; SW-TH_8P-P2.54_SMQS-04R-TP; MPN SMQS-04R-TP; LCSC Part C5299505
U8: MCP6002-I/P; DIP-8_W7.62mm_Socket_LongPads

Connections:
+3V3: C1.1, C2.1, D2.1 (K), D3.1 (K), R17.2, R18.2, R19.2, R20.2, R21.2, R22.2, R23.2, R24.2, R51.1, R52.1, R53.1, R54.1, R55.2, R56.2, R57.2, R58.2, U8.8 (V+); also elsewhere on the board
/Input/CH1: J1.1 (In), R1.2, R2.2, R3.2, R4.2, R36.1, R37.1, R38.1, R39.1
/Input/CH2: J2.1 (In), R5.2, R6.2, R7.2, R8.2, R40.1, R41.1, R42.1, R43.1
/Input/VINA+: D1.1 (K), D2.2 (A), U1.5 (PIN5), U1.6 (PIN6), U1.7 (PIN7), U1.8 (PIN8), U3.5 (PIN5), U3.6 (PIN6), U3.7 (PIN7), U3.8 (PIN8), U5.5 (PIN5), U5.6 (PIN6), U5.7 (PIN7), U5.8 (PIN8), U8.3 (+)
/Input/VINB+: D3.2 (A), D4.1 (K), U2.5 (PIN5), U2.6 (PIN6), U2.7 (PIN7), U2.8 (PIN8), U4.5 (PIN5), U4.6 (PIN6), U4.7 (PIN7), U4.8 (PIN8), U6.5 (PIN5), U6.6 (PIN6), U6.7 (PIN7), U6.8 (PIN8), U8.5 (+)
/Input/gpio26: R33.2; also elsewhere on the board
/Input/gpio27: R34.2; also elsewhere on the board
GND: C1.2, C2.2, D1.2 (A), D4.2 (A), J1.2 (Ext), J2.2 (Ext), R9.2, R10.2, R11.2, R12.2, R13.2, R14.2, R15.2, R16.2, R25.2, R26.2, R27.2, R28.2, R35.2, R44.2, R45.2, R46.2, R47.1, R48.1, R49.1, R50.1, R59.2, R60.2, R61.2, R62.2, U8.4 (V-); also elsewhere on the board
unnamed: R1.1, R36.2, U1.1 (PIN1)
unnamed: R2.1, R37.2, U1.2 (PIN2)
unnamed: R3.1, R38.2, U1.3 (PIN3)
unnamed: R4.1, R39.2, U1.4 (PIN4)
unnamed: R8.1, R43.2, U2.1 (PIN1)
unnamed: R7.1, R42.2, U2.2 (PIN2)
unnamed: R6.1, R41.2, U2.3 (PIN3)
unnamed: R5.1, R40.2, U2.4 (PIN4)
unnamed: R9.1, R35.1, U3.1 (PIN1)
unnamed: R11.1, R44.1, U3.2 (PIN2)
unnamed: R13.1, R45.1, U3.3 (PIN3)
unnamed: R15.1, R46.1, U3.4 (PIN4)
unnamed: R10.1, R50.2, U4.1 (PIN1)
unnamed: R12.1, R49.2, U4.2 (PIN2)
unnamed: R14.1, R48.2, U4.3 (PIN3)
unnamed: R16.1, R47.2, U4.4 (PIN4)
unnamed: R17.1, R55.1, U5.1 (PIN1)
unnamed: R19.1, R56.1, U5.2 (PIN2)
unnamed: R21.1, R57.1, U5.3 (PIN3)
unnamed: R23.1, R58.1, U5.4 (PIN4)
unnamed: R18.1, R51.2, U6.1 (PIN1)
unnamed: R20.1, R52.2, U6.2 (PIN2)
unnamed: R22.1, R53.2, U6.3 (PIN3)
unnamed: R24.1, R54.2, U6.4 (PIN4)
unnamed: R28.1, R62.1, U7.1 (PIN1)
unnamed: R27.1, R61.1, U7.2 (PIN2)
unnamed: R26.1, R60.1, U7.3 (PIN3)
unnamed: R25.1, R59.1, U7.4 (PIN4)
unnamed: R29.2, R30.2, R31.2, R32.2, R63.1, R64.1, R65.1, R66.1, U7.5 (PIN5), U7.6 (PIN6), U7.7 (PIN7), U7.8 (PIN8), U8.6 (-)
unnamed: R33.1, U8.1, U8.2 (-)
unnamed: R32.1, R63.2, U9.1 (PIN1)
unnamed: R31.1, R64.2, U9.2 (PIN2)
unnamed: R30.1, R65.2, U9.3 (PIN3)
unnamed: R29.1, R66.2, U9.4 (PIN4)
unnamed: R34.1, U8.7, U9.5 (PIN5), U9.6 (PIN6), U9.7 (PIN7), U9.8 (PIN8)

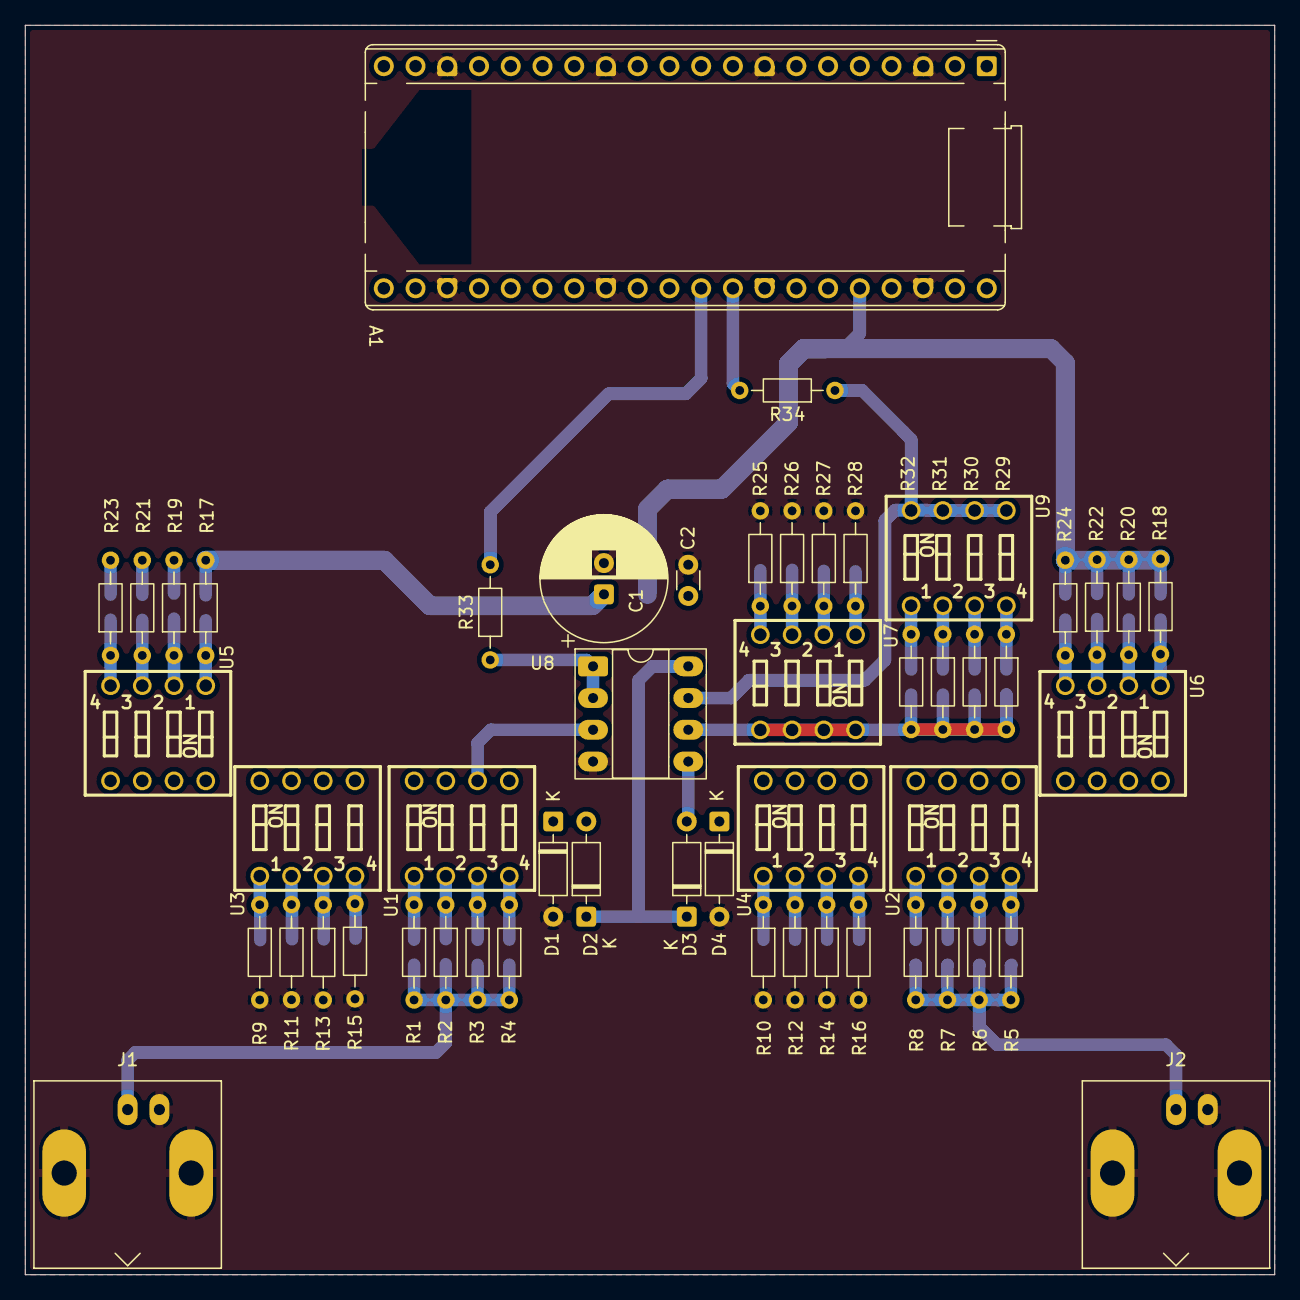
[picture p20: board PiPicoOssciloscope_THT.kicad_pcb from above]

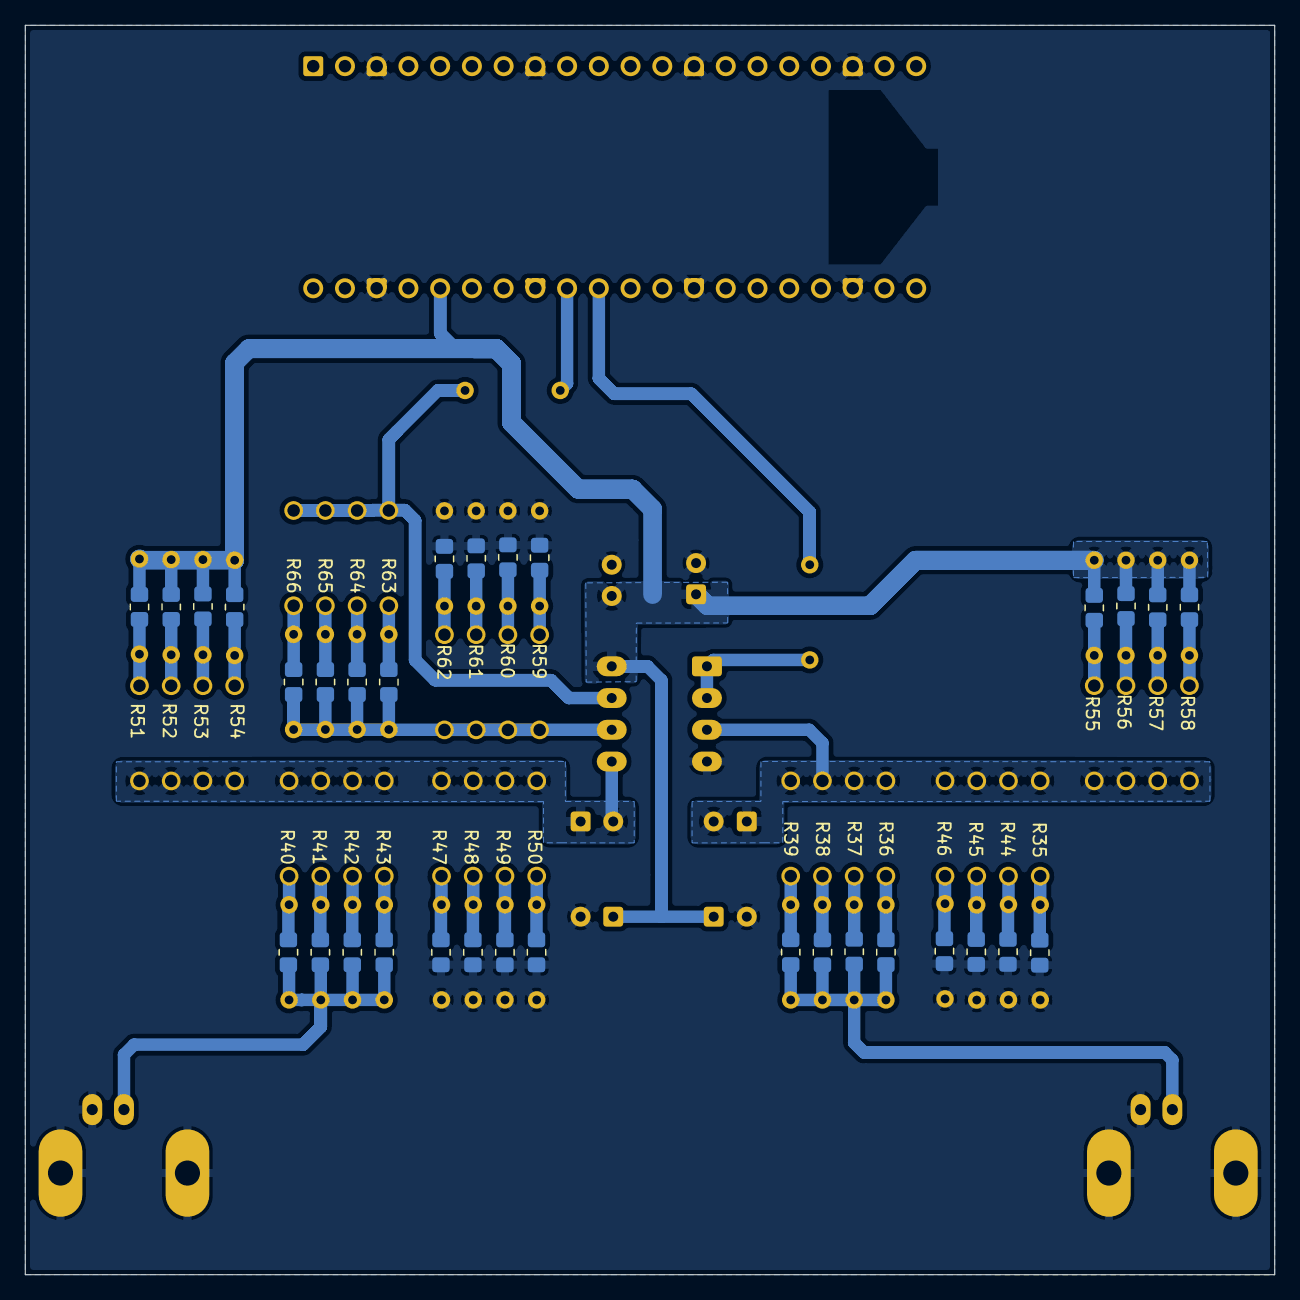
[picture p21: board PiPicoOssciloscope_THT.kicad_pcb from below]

Board: 2 copper layers, 100.0 x 100.0 mm, 84 parts (32 on the bottom side), 43 nets.

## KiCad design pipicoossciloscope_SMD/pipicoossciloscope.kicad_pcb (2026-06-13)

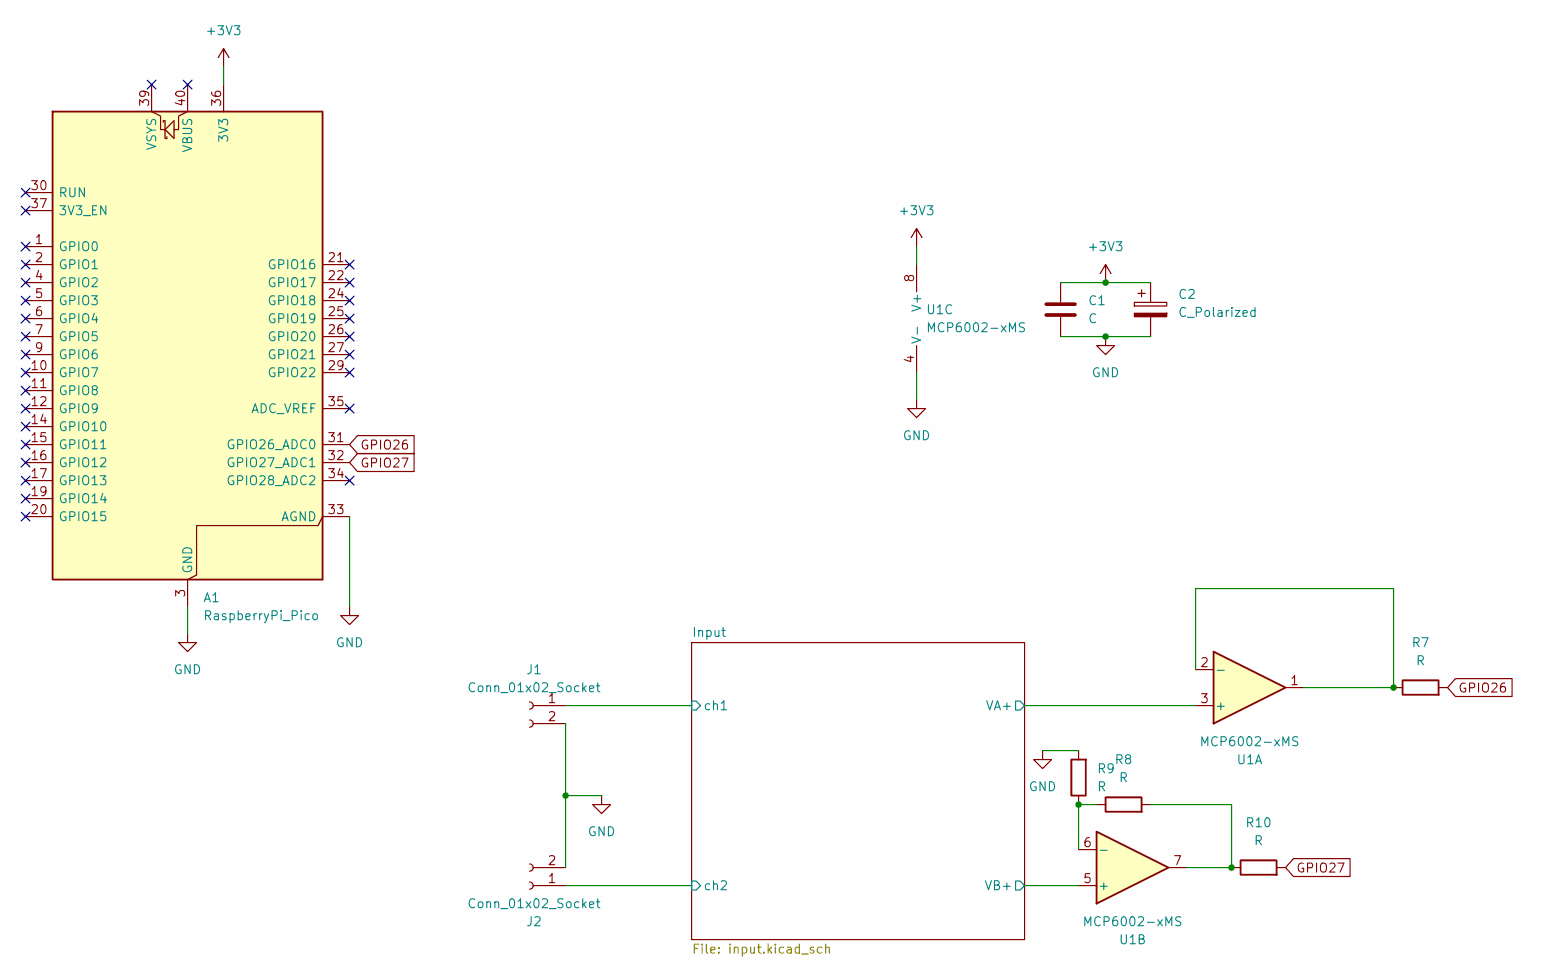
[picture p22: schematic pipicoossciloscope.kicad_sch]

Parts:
A1: RaspberryPi_Pico; RaspberryPi_Pico_Common_Unspecified
C1: C; C_1206_3216Metric_Pad1.33x1.80mm_HandSolder
C2: C_Polarized; CP_Elec_4x5.4
J1, J2: Conn_01x02_Socket; PinSocket_1x02_P2.54mm_Vertical
R7, R8, R9, R10: R; R_1206_3216Metric_Pad1.30x1.75mm_HandSolder
U1: MCP6002-xMS; MSOP-8_3x3mm_P0.65mm

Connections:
+3V3: A1.36 (3V3), C1.1, C2.1, U1.8 (V+); also elsewhere on the board
/Input/VA+: U1.3 (+); also elsewhere on the board
/Input/VB+: U1.5 (+); also elsewhere on the board
/Input/ch1: J1.1; also elsewhere on the board
/Input/ch2: J2.1; also elsewhere on the board
GND: A1.3 (GND), A1.8 (GND), A1.13 (GND), A1.18 (GND), A1.23 (GND), A1.28 (GND), A1.33 (AGND), A1.38 (GND), C1.2, C2.2, J1.2, J2.2, R9.2, U1.4 (V-); also elsewhere on the board
GPIO26: A1.31 (GPIO26_ADC0), R7.2
GPIO27: A1.32 (GPIO27_ADC1), R10.2
unnamed: R8.2, R10.1, U1.7
unnamed: R7.1, U1.1, U1.2 (-)
unnamed: R8.1, R9.1, U1.6 (-)

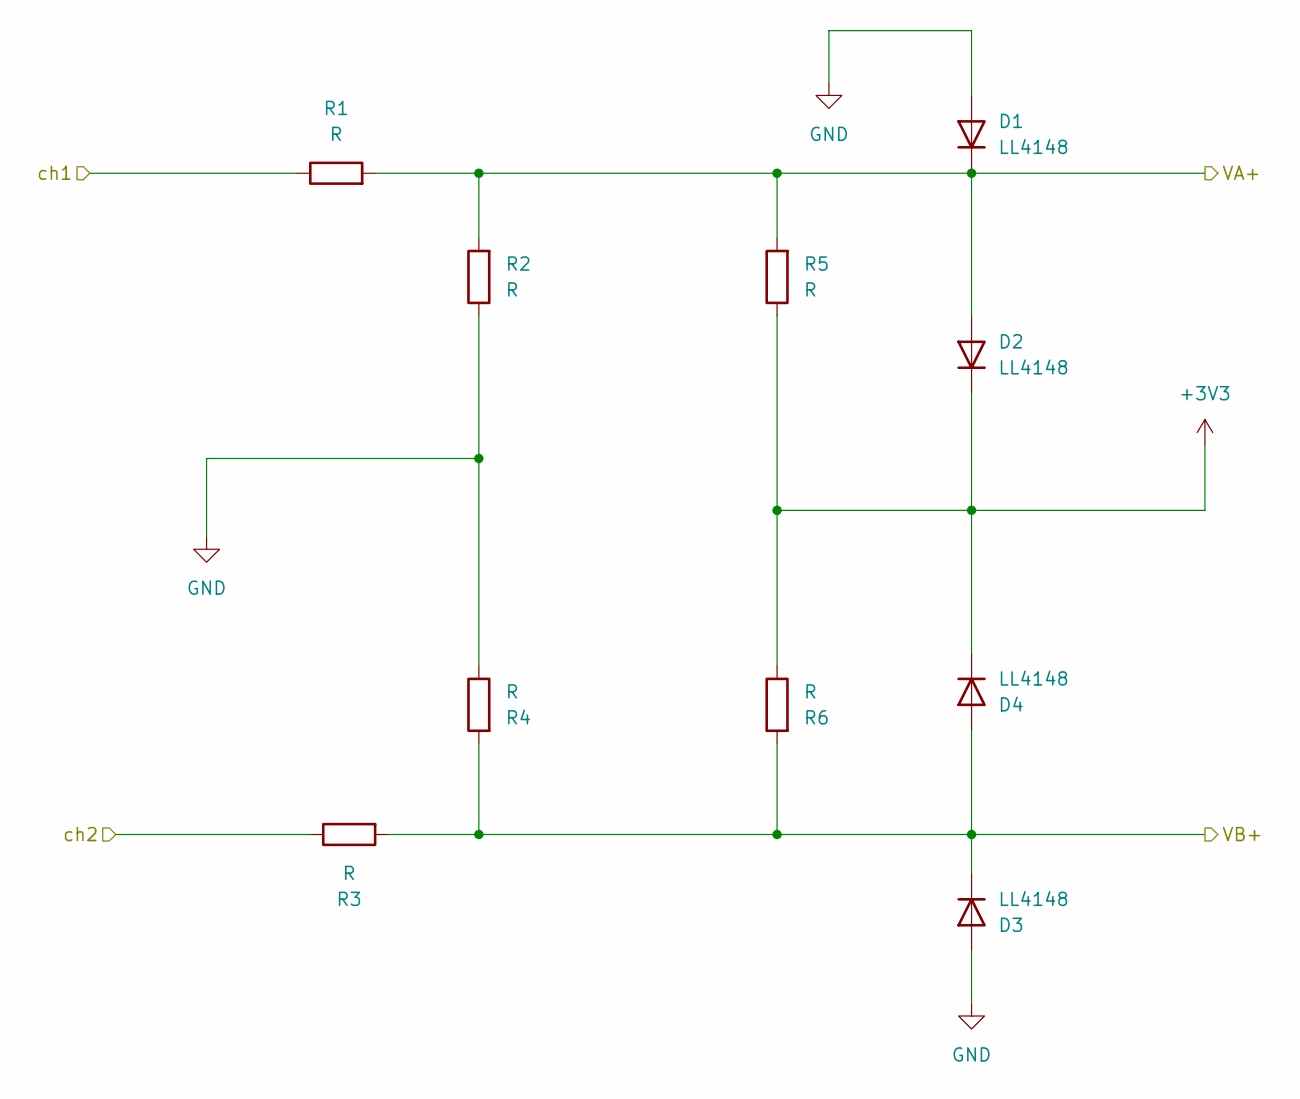
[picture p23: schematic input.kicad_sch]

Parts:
D1, D2, D3, D4: LL4148; D_MiniMELF_Handsoldering
R1, R2, R3, R4, R5, R6: R; R_1206_3216Metric_Pad1.30x1.75mm_HandSolder

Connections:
+3V3: D2.1 (K), D4.1 (K), R5.1, R6.1; also elsewhere on the board
/Input/VA+: D1.1 (K), D2.2 (A), R1.2, R2.2, R5.2; also elsewhere on the board
/Input/VB+: D3.1 (K), D4.2 (A), R3.2, R4.2, R6.2; also elsewhere on the board
/Input/ch1: R1.1; also elsewhere on the board
/Input/ch2: R3.1; also elsewhere on the board
GND: D1.2 (A), D3.2 (A), R2.1, R4.1; also elsewhere on the board

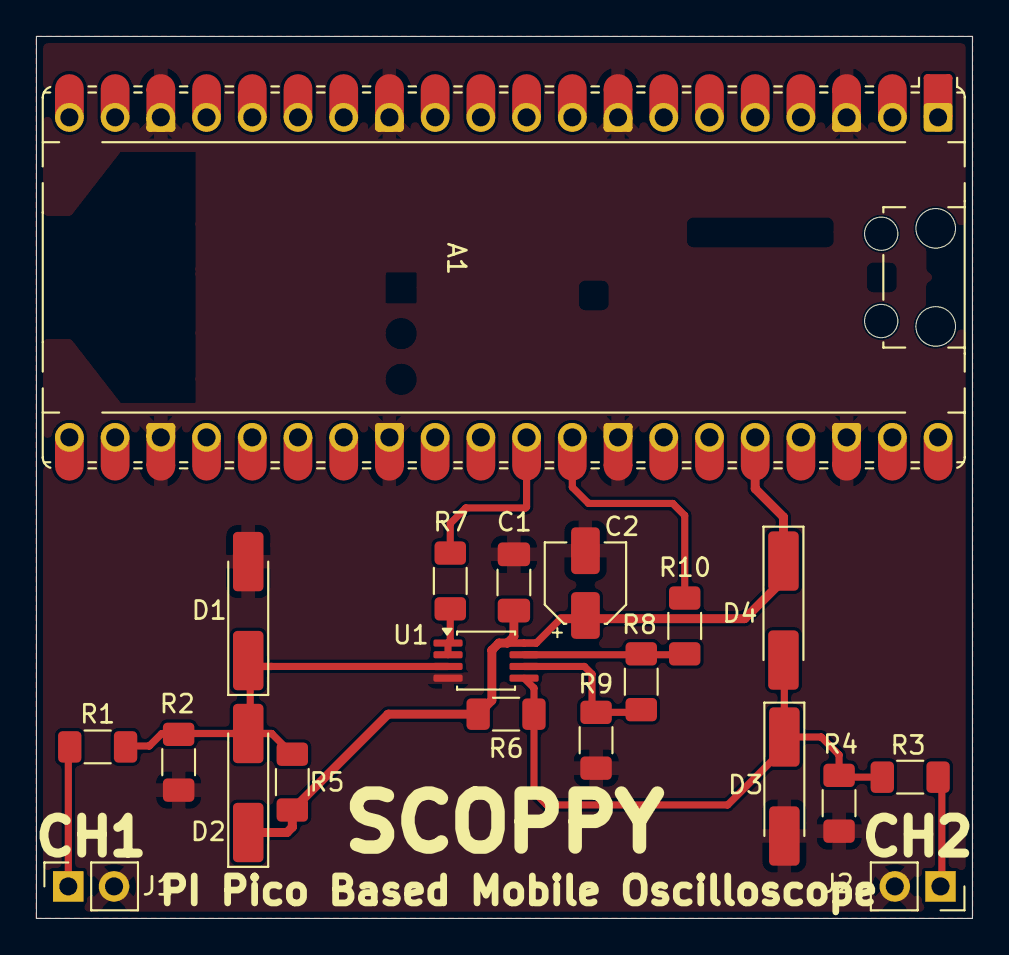
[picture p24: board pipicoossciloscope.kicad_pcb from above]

Board: 2 copper layers, 52.0 x 49.0 mm, 20 parts (0 on the bottom side), 11 nets.

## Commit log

2026-06-13 SMD scopy update.
    [input.kicad_sch, pipicoossciloscope.csv, pipicoossciloscope.kicad_pcb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]
2026-06-13 THT updated
    [Input.kicad_sch, PiPicoOssciloscope_THT.kicad_pcb, PiPicoOssciloscope_THT.kicad_sch]
2026-06-14 updated the bnc connector
    [Input.kicad_sch, PiPicoOssciloscope_THT.kicad_pcb]
